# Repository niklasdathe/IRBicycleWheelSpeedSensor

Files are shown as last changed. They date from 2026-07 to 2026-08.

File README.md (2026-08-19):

# IR Spoke Sensor





Configurable 940 nm through-beam spoke sensor for a Seeed Studio XIAO
ESP32-S3. A discrete analog front end restores a 25-50 kHz optical carrier;
ESP-IDF RMT detects its interruption and learns the wheel's spoke pattern.

This repository is the wheel-speed-sensor subsystem of
[BicycleOBU](https://github.com/niklasdathe/BicycleOBU). The
[online Interactive BOM](https://niklasdathe.github.io/IRBicycleWheelSpeedSensor/)
is generated directly from the authoritative KiCad PCB.

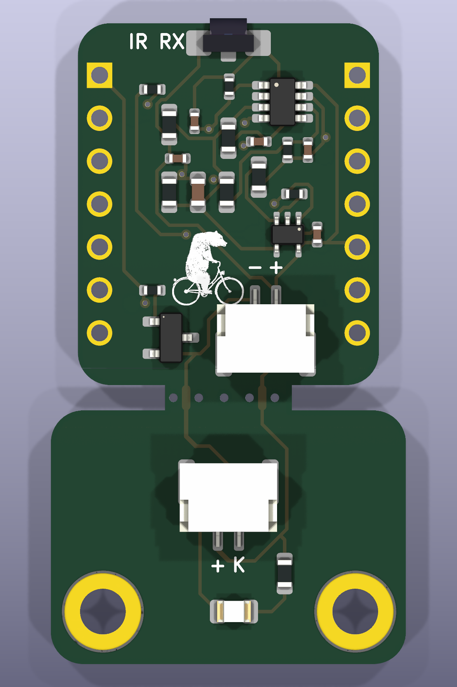
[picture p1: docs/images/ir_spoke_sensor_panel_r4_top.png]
Hardware V0.1 receiver and breakaway emitter panel


## Status

**Hardware V0.1 (KiCad CAD revision R4) was ordered and is preserved as a
[GitHub release](https://github.com/niklasdathe/IRBicycleWheelSpeedSensor/releases/tag/V0.1).
`main` is now hardware V0.2-dev; physical validation is still open for V0.1.**

| Area | Current evidence |
|---|---|
| Hardware | KiCad 10 ERC: 0 errors, 3 known library-sync warnings; DRC: 0 violations, 0 unconnected pads |
| Connectivity | 70 schematic endpoints, PCB pad nets and SPICE topology cross-checked |
| Simulation | Python transient, 10,000-case sweep and ngspice cross-check pass |
| Firmware | Portable core, RMT/CAN adapters and BLE CSC component implemented; ESP32-S3 target build passes, HIL pending |
| Manufacturing | Versioned JLC Gerber/BOM/CPL package generated; assembly-preview approval pending |
| Physical performance | Sunlight, alignment, contamination, vibration and power tests pending |

Do not treat simulation as production validation. The remaining gates are
listed in [TODO.md](TODO.md).

## Start here

| Goal | Guide |
|---|---|
| Understand the signal chain | [System overview](docs/system_overview.md) |
| Open the design or run the simulator | [Getting started](docs/getting_started.md) |
| Change configuration, firmware or captured CAD | [Development workflow](docs/development.md) |
| Order or review the PCB | [Manufacturing](docs/manufacturing.md) |
| Inspect or place components | [Interactive BOM](docs/interactive_bom.html) |
| Bring up and correlate a prototype | [Bring-up and test](docs/bringup.md) |
| Trace a requirement to evidence | [Verification matrix](requirements/verification_matrix.md) |
| Find a technical reference | [Documentation index](docs/README.md) |

## Hardware V0.1 at a glance

| Property | V0.1 value |
|---|---|
| Optical path | 940 nm VSMB1940X01 emitter to VEMD10940FX01 photodiode |
| Carrier | 25-50 kHz runtime range; 38 kHz default; 50% duty |
| Receiver | TLV9062 TIA/band-pass, TLV7011 Schmitt comparator |
| MCU interface | GPIO1 RMT TX, GPIO2 RMT RX with carrier demodulation |
| Wheel design range | 16-48 spokes; 60 km/h requirement, 80 km/h stress calculation |
| Receiver outline | 17.8 x 21.4 mm XIAO outline |
| Emitter outline | 21 x 15 mm, two M2.5 holes |
| Panel | Two-layer PCB with one routed mouse-bite breakaway tab |
| Remote link | 600 mm two-conductor JST-GH harness after snap-off |
| Optional interface | Official XIAO MCP2515 CAN expansion; disabled by default |
| BLE interface | Wheel-only Bluetooth Cycling Speed and Cadence Sensor (`0x1816`) |

## One-command entry points

```powershell
.\Open-IR-Spoke-Sensor.cmd
.\Open-Interactive-BOM.cmd
py -3.14 simulation\local_server.py
powershell -ExecutionPolicy Bypass -File tests\run_all.ps1
powershell -ExecutionPolicy Bypass -File hardware\export_jlc.ps1 -Revision V0.2
```

The KiCad launcher also starts the InteractiveHtmlBom watcher at
`http://127.0.0.1:8766/`; every complete PCB save regenerates and reloads the
browser view. The simulator opens at `http://127.0.0.1:8765/`. Disposable
simulation evidence is written under ignored `build/`.

## Source of truth

| Concern | Authoritative source |
|---|---|
| Tunable system values | [`config/system.json`](config/system.json) |
| Pins and electrical nets | [`hardware/connectivity.json`](hardware/connectivity.json) |
| Parts, fields and procurement | [`hardware/component_catalog.json`](hardware/component_catalog.json) |
| Captured schematic and routing | [`hardware/ir_spoke_link/layout_manifest.json`](hardware/ir_spoke_link/layout_manifest.json) |
| Requirements | [`requirements/requirements.yaml`](requirements/requirements.yaml) |
| Project paths and revision | [`project_manifest.json`](project_manifest.json) |
| Hardware/software versions | [`docs/versioning.md`](docs/versioning.md) |
| Changes between releases | [`CHANGELOG.md`](CHANGELOG.md) |

Generators restore the captured user layout and must not synthesize, remove or
reroute tracks. See [CONTRIBUTING.md](CONTRIBUTING.md) before changing CAD or
generated files.

## License

No project license has been selected yet. Until one is added, the repository
must not be presented as granting open-hardware, software or documentation
reuse rights.

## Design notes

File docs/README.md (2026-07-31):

# Documentation

Start with the row that matches the job in front of you.

## Task guides

| Task | Use this | Result |
|---|---|---|
| Learn what the sensor does | [System overview](system_overview.md) | Signal chain, modulation and boundaries |
| Set up and run the project | [Getting started](getting_started.md) | KiCad, simulator and complete checks |
| Change code, parameters or CAD | [Development workflow](development.md) | Correct source, generator and acceptance gate |
| Fabricate or assemble hardware V0.1 | [Manufacturing](manufacturing.md) | JLC package and review checklist |
| Identify a hardware or software release | [Versioning](versioning.md) | Independent version/tag rules |
| Locate and place components | [Interactive BOM workflow](interactive_bom.md) | Live KiCad-synced HTML BOM |
| Test a physical prototype | [Bring-up and test](bringup.md) | Testpoint sequence and pass evidence |

## Engineering references

| Subject | Reference |
|---|---|
| RMT versus MCPWM decision | [ADR-001](architecture_decision.md) |
| RMT field-to-datasheet traceability | [RMT traceability](rmt_traceability.md) |
| Model and generator relationships | [Executable relationships](model_relationships.md) |
| KiCad/SPICE net contract | [Connectivity contract](connectivity_contract.md) |
| Threshold, testpoints and daylight filter | [Debug and threshold policy](debug_and_threshold.md) |
| Power model | [Power budget](power_budget.md) |
| Optional XIAO CAN interface | [CAN interface](can_interface.md) |
| JLC/Konnect setup | [Konnect and JLCPCB](konnect_jlcpcb.md) |
| Diode assembly polarity | [JLC diode orientation](jlc_diode_orientation.md) |
| Documentation design references | [Reference projects](reference_projects.md) |

## Evidence and machine-readable data

| Artifact | Purpose |
|---|---|
| [`requirements/requirements.yaml`](../requirements/requirements.yaml) | Verifiable requirement statements |
| [Verification matrix](../requirements/verification_matrix.md) | Requirement test and evidence mapping |
| [`datasheet_values.json`](datasheet_values.json) | Extracted limits used by checks |
| [Sources](sources.md) | Primary-source index |
| [`zotero_links.json`](zotero_links.json) | Zotero keys and local attachments |
| [Interactive HTML BOM](interactive_bom.html) | Searchable board/part placement view |
| [Technical simulator reference](../local_simulator/technical.html) | Compact live-model trace definitions |
| [Hardware V0.1 panel image](images/ir_spoke_sensor_panel_r4_top.png) | Ordered CAD R4 PCB |
| [Schematic PDF](../hardware/ir_spoke_link/ir_spoke_link_schematic.pdf) | Current generated schematic |
| [Board STEP](../hardware/ir_spoke_link/ir_spoke_link.step) | Mechanical exchange model |

## Information ownership

Each fact has one owner:

- `config/system.json` owns tunable values.
- `hardware/connectivity.json` owns electrical topology.
- `hardware/component_catalog.json` owns part and procurement metadata.
- `hardware/ir_spoke_link/layout_manifest.json` owns captured layout hashes.
- `requirements/requirements.yaml` owns acceptance requirements.
- `project_manifest.json` owns canonical paths and revision.

Other pages explain or link these values; they must not become independent
configuration sources. `tools/audit_project.py` checks canonical paths,
relative documentation links and index coverage.

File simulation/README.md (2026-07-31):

# Simulation

`ir_spoke_sim.py` is the linked system model. It reads
`../config/system.json`. The local API imports the model directly; command-line
runs write disposable evidence to `../build/simulation/`.

`ir_spoke_link.cir` is the ngspice/KiCad-compatible circuit model. It includes
the remote LED and cable resistance, VEMD10940FX01 photocurrent/capacitance,
TLV9062 finite-bandwidth TIA and active band-pass, TLV7011 hysteretic
comparator, ESP32 load, optional XIAO CAN load and input network. Its physical nets are generated from
`hardware/connectivity.json`. Both batch and local simulations fail when the
generated topology hash is stale.

The fast TLV9062 model in `models/TLV9062_typ_ngspice.lib` uses the
datasheet-typical 100 dB open-loop gain, 10 MHz GBW and 40 mV light-load output
headroom. TI's original PSpice Rev. E ZIP is retained for short sign-off
cases; its switch-heavy model is intentionally not used for the interactive
wheel transient.
`validate_ngspice.py` runs the complete circuit and bounds TIA, band-pass,
blockage-demodulation and current results against the Python reference.

`local_server.py` serves `http://127.0.0.1:8765/`. The HTML contains no
second electrical model: `/api/simulate` calls `ir_spoke_sim.simulate()`
directly. Every window is phase-aligned to contain a complete spoke blockage.
Reset reloads `config/system.json`; code export runs the same transient and
returns a C header containing the selected RMT and adaptive-map values.

Current/power traces separate LED, ESP32, AFE and optional CAN loads and include carrier
edges, a Wi-Fi TX burst, configurable CPU activity, VREF startup and local
decoupling inrush. The local UI exposes CAN enable and dominant-bus duty and
uses the same values when generating the experiment header. See
`docs/power_budget.md` for assumptions and limitations.

Run:

```powershell
py -3.14 simulation/ir_spoke_sim.py
py -3.14 simulation/validate_ngspice.py
py -3.14 tools/validate_kicad_netlist.py
py -3.14 simulation/local_server.py
```

The numerical noise source combines ambient/dark-current shot noise, TIA
feedback-resistor Johnson noise, op-amp current noise, an input-referred
approximation of op-amp voltage noise, and the separately adjustable
environmental interference term. The model has no proprietary integrated
receiver behavior. Beam profile, contamination, sunlight spectra and
mechanical alignment still require prototype tests before release.

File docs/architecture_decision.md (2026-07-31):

# ADR-001: RMT RX instead of MCPWM Capture for the raw comparator carrier

Status: accepted for the current hardware.

The custom analog front end intentionally stops at a Schmitt comparator. Its
output is therefore a clean logic carrier at the selected 25–50 kHz transmit
frequency whenever the optical path is clear and stops while a spoke blocks
the beam.

ESP32-S3 RMT is the better fit for that signal because the peripheral supports
TX carrier modulation, RX carrier demodulation, input filtering and
symbol-duration capture. The firmware uses ESP-IDF's official channel,
copy-encoder, carrier, callback, receive and transmit abstractions instead of
register access. It receives missing-carrier windows without processing every
carrier edge in an application ISR.

The RX demodulator frequency is derived at runtime as a configurable ratio of
the selected TX frequency. The default 0.66 follows Espressif's documented
38 kHz TX / 25 kHz RX tolerance example and is not a second fixed frequency.
TX and RX GPIO, RMT resolution, channel memory, TX queue depth, carrier duty,
RX ratio/duty, minimum pulse, blockage acceptance and link-loss timeout are all
members of the validated runtime configuration. Callback timestamps are
reconstructed from captured RMT symbol durations instead of assigning the
callback time to every event.

MCPWM Capture has a high-resolution APB-clock timestamp and is excellent when
the input is already a baseband edge. On ESP32-S3 its requested resolution is
ignored because the capture timer uses the APB source. Using it here would
either expose every carrier edge to the capture path or require another analog
envelope detector. That adds parts without improving spoke-time accuracy.

Revisit this decision only if a future board adds an external envelope detector,
or if RMT resources are consumed by another subsystem.

The 25–50 kHz range is an engineering constraint of the installed analog
filter, not a protocol requirement. Values outside it are rejected by
`ir_spoke_config_validate()`.

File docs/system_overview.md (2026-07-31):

# System overview

## Purpose

The sensor measures spoke passages by shining a modulated infrared beam across
the wheel. A spoke briefly blocks the beam. The receiver converts the missing
carrier interval into a timestamped digital event for an ESP32-S3.

This is carrier-presence sensing, not an IR data protocol.

## Signal chain

```mermaid
flowchart LR
  A["ESP32-S3 RMT TX<br>25-50 kHz"] --> B["S8050 LED driver"]
  B --> C["940 nm side-view LED"]
  C --> D{"Spoke blocks beam?"}
  D --> E["VEMD10940FX01<br>photodiode"]
  E --> F["TLV9062 TIA"]
  F --> G["TLV9062 band-pass"]
  G --> H["TLV7011 comparator<br>with hysteresis"]
  H --> I["ESP32-S3 RMT RX<br>carrier demodulation"]
  I --> J["Blockage detector"]
  J --> K["Spoke-count inference<br>adaptive interval LUT"]
  K --> L["Application / optional CAN"]
```

The main board and emitter are initially one routed panel. After functional
test, the emitter snaps off and reconnects through the two-conductor JST-GH
harness.

## Modulation

RMT TX drives the LED with a 50% duty square carrier. With a clear beam, the
photodiode and analog front end recover that periodic energy and the comparator
produces logic edges. A spoke removes several carrier cycles. RMT RX
demodulation converts that carrier loss into a single interval for the
detector.

Modulation improves reliability because:

- the AC-coupled band-pass rejects DC and slowly changing ambient light;
- energy in a known frequency range is easier to distinguish from broadband
  noise than unmodulated intensity;
- comparator hysteresis suppresses repeated transitions near threshold;
- RMT filters and demodulates in hardware, so the application processes
  blockage intervals instead of every carrier edge.

The photodiode includes a daylight-blocking optical filter, but sunlight still
contains 940 nm energy. Modulation reduces ambient sensitivity; it does not
remove the need for physical sunlight testing.

## Timing and adaptation

The configured design range is 16-48 spokes at up to 60 km/h, with an 80 km/h
stress calculation. The detector accepts only blockage widths inside the
configured interval. Accepted timestamps feed a portable pattern module that:

1. rejects outliers;
2. estimates the repeating spoke count;
3. maintains one expected interval per spoke in a bounded LUT;
4. updates the LUT continuously with exponential adaptation.

Uniformly spaced spokes do not contain enough information to identify an
absolute spoke index. The implementation reports confidence and keeps adapting
instead of requiring a manual calibration.

## Model boundary

The executable models include wheel geometry, optical coupling, photodiode
current/capacitance, analog bandwidth and noise, comparator behavior, RMT
timing, power transients and optional CAN load. Python supplies the interactive
and tolerance model; ngspice cross-checks the electrical transient.

They do not prove real beam alignment, lens/fixture tolerances, spectral
sunlight rejection, water/dirt behavior, cable vibration or component aging.
Those are explicit prototype tests in [Bring-up and test](bringup.md).

## Interfaces

| Boundary | Contract |
|---|---|
| Tunable model to generated code | `config/system.json` |
| Schematic/PCB to SPICE | `hardware/connectivity.json` |
| Comparator to MCU | GPIO2, RMT RX symbols |
| Detector to pattern learner | accepted event timestamp and blockage width |
| Pattern learner to application | count, confidence, phase and interval LUT |
| Application to CAN adapter | transport-independent fixed telemetry frame |

Detailed interfaces are in
[`firmware/components/ir_spoke_core`](../firmware/components/ir_spoke_core/)
and [Executable relationships](model_relationships.md).

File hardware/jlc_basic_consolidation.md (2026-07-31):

# JLCPCB part-class and consolidation audit

Checked 2026-07-28 against the JLCPCB Parts API snapshot in
`hardware/jlcpcb_parts_snapshot.json`.

| Group | Result |
|---|---|
| Basic retained | Q1; R2, R3, R4, R5, R7, R9, R10, R11; C1, C3, C5, C6 |
| Extended retained for analog value/dielectric | R6 16 kOhm, R8 560 kOhm, C2 120 pF C0G, C4 4.7 pF C0G |
| Extended retained for electrical/optical behavior | D1, D2, U1, U2 |
| Extended retained for mechanics | J3 and J4, consolidated to one identical JST-GH part |
| Extended retained for LED current | R1 39 Ohm; no exact in-stock Basic result was returned |

The active devices are model inputs, not generic placeholders. Replacing
TLV9062, TLV7011, VEMD10940FX01 or VSMB1940X01 requires a new
datasheet-value extraction, tolerance sweep, transient simulation and optical
alignment review. J3/J4 and their cable parts are already consolidated.

The current placed panel has 24 placements in 20 grouped BOM rows. Common
passives and Q1 are Basic. Header sockets, M2.5 holes and test pads are DNI.

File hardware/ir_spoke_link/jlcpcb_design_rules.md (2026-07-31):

# JLCPCB manufacturing profile

Conservative 2-layer, 1 oz rules used by this project:

- Track width / clearance: 0.15 / 0.15 mm (fab minimum is 0.10 / 0.10 mm).
- Signal vias: 0.60 mm diameter, 0.30 mm drill.
- Via-to-track: 0.25 mm (fab minimum 0.20 mm).
- Different-net SMD pad clearance: 0.20 mm (fab minimum 0.15 mm).
- Copper-to-board-edge: 0.30 mm.
- Minimum component body-to-edge target: 2.5 mm where the XIAO carrier
  geometry allows; the optical edge-facing parts require explicit DFM review.
- 0402 is the smallest passive footprint used. 0603 is used for the LED current
  resistor to retain pulse-power margin.
- IPC-7351 medium-density courtyards; no via-in-pad.
- Exactly two copper layers, 1.6 mm FR-4 and 1 oz outer copper are encoded in
  the R4 order definition.
- The receiver is 17.8 x 21.4 mm; the transmitter is 21 x 15 mm. Both have
  four 1.905 mm-radius corners.
- One 7.5 x 1.5 mm routed tab joins the boards. Five 0.5 mm NPTH drills at
  1.5 mm pitch form the break line. Two 0.25 mm temporary links cross between
  the drills and are intentionally severed when the tab is snapped.
- The combined customer board is 21 x 37.9 mm and requires online DFM review
  of the mouse-bite tab before ordering.
- BOM, CPL, Gerber job, copper, mask, silkscreen, outline and drill files are
  included by the versioned `IR_Spoke_Sensor_R4_2L` export workflow.

Sources are recorded in `docs/sources.md`. Always re-run JLCPCB online DFM and
re-check live component stock immediately before ordering.

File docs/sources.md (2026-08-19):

# Sources and assumptions

## Geometry

- 700C / 29-inch class effective rolling diameter assumed: 0.702 m.
- Maximum design speed: 60 km/h; stress case: 80 km/h.
- 32 round spokes, 2.0 mm projected width.
- Optical crossing radius: 0.25 m from hub.

At 60 km/h this gives 7.56 wheel revolutions/s, 241.9 spoke passages/s,
approximately 168 µs blocked per spoke and 3.97 ms clear between spokes.

## Primary references

- Bluetooth SIG, *Cycling Speed and Cadence Profile 1.0* (with mandatory Errata
  Correction 23224): https://www.bluetooth.com/specifications/specs/cycling-speed-and-cadence-profile-1-0/
- Bluetooth SIG, *Cycling Speed and Cadence Service 1.0.1*:
  https://www.bluetooth.com/specifications/specs/cycling-speed-and-cadence-service/

- JLCPCB PCB capabilities:
  https://jlcpcb.com/capabilities/pcb-capabilities/
- JLCPCB PCB assembly FAQ and Basic/Extended classification:
  https://jlcpcb.com/help/article/pcb-assembly-faqs
- JLCPCB assembly DFM terms:
  https://jlcpcb.com/help/article/terms-and-conditions-of-jlcpcb-assembly-service
- Vishay VSMB1940X01 940 nm IR LED, LCSC C3151600:
  https://www.lcsc.com/product-detail/C3151600.html
- Vishay VEMD10940FX01 side-view photodiode, LCSC C7104273:
  https://www.vishay.com/docs/84217/vemd10940fx01.pdf
- Vishay packaging and tape orientation (VSMB1940X01 Fig. 32):
  https://www.vishay.com/docs/80090/packaging.pdf
- JLCPCB placement rotation and zero-orientation rules:
  https://jlcpcb.com/help/article/pick-place-file-for-pcb-assembly
  https://jlcpcb.com/help/article/pcb-assembly-faqs-part-2
- TI TLV9062 10 MHz RRIO dual op amp, LCSC C2867884:
  https://www.ti.com/lit/ds/symlink/tlv9062.pdf
- TI TLV7011 nanopower comparator, LCSC C193688:
  https://www.ti.com/lit/ds/symlink/tlv7011.pdf
- JST GH 1.25 mm side-entry secure-lock header
  SM02B-GHS-TB(LF)(SN), LCSC/JLCPCB C189893:
  https://www.jst-mfg.com/product/pdf/eng/eGH.pdf
- Live LCSC listing for SM02B-GHS-TB(LF)(SN):
  https://www.lcsc.com/product-detail/wire-to-board-connector_jst-sm02b-ghs-tb-lf-sn_C189893.html
- ESP32-S3 RMT peripheral:
  https://docs.espressif.com/projects/esp-idf/en/stable/esp32s3/api-reference/peripherals/rmt.html
- ESP32-S3 datasheet, revision 2.2:
  https://documentation.espressif.com/esp32-s3_datasheet_en.pdf
- Espressif ESP32-S3 hardware design guidelines:
  https://documentation.espressif.com/projects/esp-hardware-design-guidelines/en/latest/esp32s3/schematic-checklist.html
- Seeed Studio XIAO ESP32-S3 getting started / 3V3 capacity:
  https://wiki.seeedstudio.com/xiao_esp32s3_getting_started/
- Official Seeed Studio XIAO CAN Bus Expansion board, pin map and design:
  https://wiki.seeedstudio.com/xiao-can-bus-expansion/
- Microchip MCP2515 stand-alone CAN controller:
  https://files.seeedstudio.com/wiki/xiao_can_bus_board/MCP2515-Stand-Alone-CAN-Controller-with-SPI-200018-708845.pdf
- TI SN65HVD230 3.3 V CAN transceiver:
  https://www.ti.com/lit/ds/symlink/sn65hvd230.pdf
- JLCPCB V-cut panelization standards:
  https://jlcpcb.com/blog/v-cut-panelization-standards
- JLCPCB Gerber preparation:
  https://jlcpcb.com/help/article/gerber-files-preparation

## Engineering status

LCSC stock and JLCPCB library class are live commercial data and can change
without notice. The BOM captures the checked candidate set, but it is not a
purchase guarantee. Active performance parts are Extended; common passives and
the S8050 driver are Basic. Direct-sun, alignment, vibration, dirt and water
tests are required before treating the link as safety-related.

The official CAN expansion's Eagle design identifies MCP2515 plus
SN65HVD230; its D6/D7/D8/D9/D10 assignment is disjoint from this sensor's
D0/D1 RMT assignment. The optional CAN power case is included in the
simulation even though the CAN board is not populated on the sensor panel.

The VEMD10940FX01 datasheet specifies a daylight-blocking filter matched to
830-950 nm emitters. This reduces visible/daylight loading but cannot reject
the 940 nm content of direct sunlight; electrical AC filtering and physical
sunlight tests remain necessary.

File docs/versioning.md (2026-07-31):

# Versioning and releases

Hardware and software have independent version streams.

| Stream | Version file | GitHub tag format | Meaning |
|---|---|---|---|
| Hardware | `hardware/VERSION` | `V0.1`, `V0.2`, ... | Ordered or manufactured PCB baseline |
| Software | `firmware/VERSION` | `SW-V0.1.0`, ... | Tested firmware release |

KiCad CAD revision `R4` is an internal design identifier. Hardware `V0.1` is
the ordered release made from that CAD revision. A hardware release never
implies that firmware with a similar number was released.

The `V0.1` annotated Git tag and GitHub release are immutable troubleshooting
anchors. The release contains the combined order package, Gerber archive,
PCBA archive, individual BOM/CPL/order files, DRC evidence, courtyard reference
and SHA-256 checksums.

Development after the ordered baseline uses `V0.2-dev` in
`hardware/VERSION`. Its changelog section records differences relative to
`V0.1`; only an intentionally approved manufacturing state becomes tag `V0.2`.

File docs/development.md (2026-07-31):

# Development workflow

## Rule: change the owner, not a consumer

| Concern | Authoritative input | Generated or checked consumers |
|---|---|---|
| Timing, optical, analog and power values | `config/system.json` | C headers, SPICE parameters, Python/UI defaults |
| Pins and nets | `hardware/connectivity.json` | KiCad audit and SPICE connectivity include |
| Parts and fields | `hardware/component_catalog.json` | schematic/PCB fields, BOM, footprint and Konnect data |
| Requirements | `requirements/requirements.yaml` | verification matrix and tests |
| Manual CAD state | live KiCad files | captured layout templates and hashes |

Never edit a generated consumer to override its source.

## Parameter change

1. Edit `config/system.json`.
2. Run `py -3.14 tools/generate_constants.py`.
3. Exercise the value in the local simulator.
4. Add or update a requirement/test if acceptance behavior changed.
5. Run `tests/run_all.ps1`.

The runtime carrier remains validated from 25-50 kHz. The generated header
provides compile-time defaults and limits; it does not replace runtime
validation.

## Firmware boundaries

`firmware/components/ir_spoke_core` is portable C99 with caller-owned state and
no heap, RTOS or ESP-IDF dependency:

| Module | Interface responsibility |
|---|---|
| `ir_spoke_config` | Validate runtime carrier and detector configuration |
| `ir_spoke_geometry` | Convert wheel geometry and speed to timing |
| `ir_spoke_detector` | Qualify blockage widths and track link state |
| `ir_spoke_pattern` | Infer count/confidence and adapt the interval LUT |
| `ir_spoke_pipeline` | Compose detector and learner without hardware access |
| `ir_spoke_can` | Encode fixed telemetry independently of transport |

`firmware/main` owns ESP-IDF RMT and optional MCP2515/SPI integration. Hardware
callbacks translate peripheral events into the portable interfaces; portable
modules do not call ESP-IDF.

## Connectivity change

1. Edit `hardware/connectivity.json`.
2. Update the schematic/PCB manually if the physical design changes.
3. Run `py -3.14 tools/generate_connectivity.py`.
4. Run `py -3.14 tools/validate_kicad_netlist.py`.
5. Run the full suite.

Simulation refuses to start when its topology hash is stale. The native KiCad
netlist, PCB pad nets and generated SPICE topology must all match.

## CAD change

The route is user-authored and protected. Generators may restore it but must
never route.

1. Open through `Open-IR-Spoke-Sensor.cmd`.
2. Make the manual schematic, placement or routing edit.
3. Save and close every KiCad editor.
4. Run:

   ```powershell
   py -3.14 hardware\ir_spoke_link\capture_layout.py
   ```

5. Review the PDF/PCB visually and run the complete suite.

6. Regenerate the README image from the captured board:

   ```powershell
   py -3.14 tools\readme_pcb_render.py --generate
   ```

`layout_manifest.json` records schematic, PCB, logical routing, raw route text,
preferences, rotations, DRC requirements and endpoint count. A component move
does not authorize automated rerouting.

The render manifest beside the PNG records both the PCB and image hashes. CI
fails when the README still shows an older captured PCB.

## Acceptance checklist

- [ ] The authoritative source changed.
- [ ] Generated files were regenerated, not manually patched.
- [ ] Relevant requirement and test still express the intended behavior.
- [ ] `tests/run_all.ps1` passes.
- [ ] CAD hashes changed only when an intentional manual CAD edit occurred.
- [ ] Physical claims remain marked unverified until measured.
- [ ] Manufacturing changes pass the [manufacturing checklist](manufacturing.md).

See [CONTRIBUTING.md](../CONTRIBUTING.md) for the concise repository policy.

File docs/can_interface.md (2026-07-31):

# Optional XIAO CAN interface

Hardware: official Seeed XIAO CAN Bus Expansion Board, SKU 105100001,
MCP2515 controller with 16 MHz crystal and SN65HVD230 3.3 V transceiver.

| XIAO pin | ESP32-S3 GPIO | CAN function | IR conflict |
|---|---:|---|---|
| D6 | 43 | MCP2515 INT | none |
| D7 | 44 | MCP2515 CS | none |
| D8 | 7 | SPI SCK | none |
| D9 | 8 | SPI MISO | none |
| D10 | 9 | SPI MOSI | none |
| D0 | 1 | IR RMT TX | CAN unused |
| D1 | 2 | IR RMT RX | CAN unused |

Default CAN bitrate: 500 kbit/s. SPI: 10 MHz, mode 0. Compile-time
`_Static_assert` checks prevent future IR/CAN pin overlap.

Interfaces:

- `ir_spoke_can`: portable frame encoding and caller-supplied send callback.
- `ir_spoke_can_mcp2515_adapter`: ESP-IDF `spi_master` and MCP2515 register
  protocol for the official board.
- `ir_spoke_rmt_adapter`: publishes one estimate frame after each accepted
  blockage when the CAN publisher is enabled.

Standard ID `0x180` payload:

| Byte | Field | Encoding |
|---:|---|---|
| 0 | inferred spoke count | unsigned |
| 1 | current spoke index | unsigned |
| 2–3 | wheel frequency | little-endian mHz |
| 4–5 | blockage duration | little-endian µs |
| 6–7 | confidence | little-endian per mille |

`config/system.json` is authoritative. `tools/generate_constants.py` writes
the pin map, oscillator, bitrate, SPI clock, enable default and CAN ID into
firmware and SPICE constants. The localhost simulator exposes CAN enable and
bus-duty inputs and plots `can_current_ma`.

Official sources and Zotero keys are recorded in
`docs/zotero_links.json`.

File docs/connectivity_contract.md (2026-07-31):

# Connectivity contract

`hardware/connectivity.json` is the canonical pin-to-net definition for both
boards and the two resistive harness conductors.

Consumers and gates:

- `hardware/ir_spoke_link/capture_layout.py` through the native netlist gate;
- the hash-verified main-board schematic/PCB layout templates;
- `tools/generate_connectivity.py` for SPICE;
- `hardware/footprint_audit.py`.

`tools/validate_kicad_netlist.py` independently asks KiCad to export its native
XML netlist and compares all 70 connected schematic pins with the manifest.
`simulation/connectivity_guard.py` hashes the manifest and refuses every batch
or local API simulation if `simulation/generated_connectivity.inc` is stale.

This catches symbol transforms, swapped active-device pins, connector mistakes,
PCB pad-net drift and stale SPICE topology. It does not prove track routing:
KiCad DRC remains the routing gate. After restoring the physical footprint
orientations and moving the correction into CPL-only rotation offsets, both
the combined receiver/emitter panel has zero findings and zero open
connections. Its layout capture
additionally freezes the 197 user segments, 12 vias and raw route-expression
SHA-256.

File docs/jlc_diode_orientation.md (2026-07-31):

# JLC diode orientation verification

JLC CPL rotation is positive counter-clockwise. JLC defines package zero from
the tape/reel orientation and requires the assembly preview and polarity marks
to be checked.

| Ref | Part | Physical KiCad zero | LCSC-owned EasyEDA package zero | CPL offset | Final CPL |
|---|---|---|---|---:|---:|
| D1 | VSMB1940X01 / C3151600 | pad 1 cathode left; pad 2 anode right | pin/pad 1 anode left; pin/pad 2 cathode right | 180° | 180° |
| D2 | VEMD10940FX01 / C7104273 | pad 1 cathode left; pad 2 mechanical center; pad 3 anode right | pin/pad 1 cathode left; pin/pad 2 mechanical center; pin/pad 3 anode right | 0° | 0° |

Electrical maps:

- D1.1 = `LED_K_REMOTE`, D1.2 = `LED_A`.
- D2.1 = `+3V3`, D2.2 = `NC_MECHANICAL`, D2.3 = `PD_ANODE`.

The LCSC package records were read from:

- `https://easyeda.com/api/products/C3151600/components?version=6.5.37`
- `https://easyeda.com/api/products/C7104273/components?version=6.5.37`

Both records identify `owner.username = lcsc`. C3151600's EasyEDA symbol maps
pin 1 to A and pin 2 to K, while KiCad's LED convention maps pad 1 to K and pad
2 to A. D1 therefore needs a CPL-only 180° correction. C7104273 maps pin 1 to
the cathode and pin 3 to the anode, so D2 needs no correction.

The generator binds each rotation rule to reference, LCSC number and MPN and
aborts if those fields no longer match. `hardware/footprint_audit.py`
independently verifies physical rotation and diode pad/net polarity. In the JLC
assembly preview, both parts must read cathode on the left and anode on the
right (`- D1 +` and `- D2 +`).

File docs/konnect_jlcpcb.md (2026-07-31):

# Konnect JLCPCB database connection

In **Konnect Settings**:

1. Leave `kicad-cli` at
   `C:\Program Files\KiCad\10.0\bin\kicad-cli.exe`.
2. Set `JLCPCB DB` to
   `%APPDATA%\konnect\jlcpcb.db`.
3. Leave `IPC Socket` empty for normal automatic discovery.
4. Keep `Transport` at `both`, click **Save**, then close the dialog.

The screenshot already shows the server running. KiCad must be open with IPC
available for live editor operations.

Konnect's effective-config API was queried after setup and returns this exact
database path plus `prefer_jlc_basic: true` and the project JLCPCB rules.

The database currently contains 21 integrity-checked rows used by this
project: 9 Basic and 12 Extended. It is deliberately a project-BOM subset,
not the complete JLCPCB catalog.

Rebuild and verify:

```powershell
py -3.14 tools\refresh_jlc_links.py
py -3.14 tools\build_konnect_jlc_db.py
py -3.14 -m unittest tests.test_system.TestSystem.test_konnect_database_matches_expected_schema_and_scope -v
```

After a rebuild, restart the Konnect server if it does not notice the replaced
SQLite file. `hardware/konnect_database_manifest.json` records scope, counts,
source timestamp and SHA-256.

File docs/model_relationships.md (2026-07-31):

# Executable relationships

| Source | Generated or checked consumers |
|---|---|
| `config/system.json` | firmware headers, SPICE parameters, Python defaults, local UI reset |
| `hardware/connectivity.json` | schematic/PCB audits, native KiCad netlist gate, SPICE topology and topology hash |
| `hardware/component_catalog.json` | schematic/PCB fields, BOM, footprint audit and JLC/Konnect metadata |
| `docs/datasheet_values.json` | model limits, requirements checks and technical documentation |
| `hardware/ir_spoke_link/*.layout.kicad_*` | byte-identical schematic/PCB/preferences regeneration |
| `hardware/ir_spoke_link/layout_manifest.json` | layout, route, rotations, DRC and net-endpoint integrity gates |
| `simulation/ir_spoke_sim.py` | local API, generated experiment header and batch evidence |
| `simulation/ir_spoke_link.cir` | ngspice cross-check against the Python transient |
| `requirements/requirements.yaml` | verification-ID coverage in `requirements/verification_matrix.md` |
| `hardware/ir_spoke_link/bom_jlcpcb.csv` | R4 export, live JLC snapshot and Konnect project database |

The combined PCB is the only emitter-board source. The breakaway transmitter is
part of the same captured board, BOM, CPL, connectivity contract and DRC gate.
Generated simulation results live under `build/`; the source tree contains no
second cached simulation dataset.

Run `tools/audit_project.py` for path/reference integrity and
`tests/run_all.ps1` for the complete executable chain.

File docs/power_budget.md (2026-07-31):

# Power budget

## Modeled 3.3 V rail

| Load | Default scenario |
|---|---:|
| ESP32-S3 + XIAO board, averaged | 60.35 mA |
| IR LED, 45.02 mA peak at 50% duty | 22.51 mA |
| S8050 base drive, 2.50 mA peak at 50% duty | 1.25 mA |
| TLV9062, TLV7011 and VREF divider | 1.246 mA |
| Optional XIAO CAN board | 0 mA (disabled by default) |
| Total steady average | 85.36 mA |
| Total coincident peak estimate | 392.27 mA |
| 3.3 V steady power | 281.69 mW |
| Estimated regulator input at 90% efficiency | 312.99 mW |

The ESP32 scenario uses the datasheet's 42.3 mA WAITI and 54.6 mA
single-core values at 160 MHz, a configurable 10% CPU-active fraction, and a
configurable 5% Wi-Fi TX fraction. The peak aligns the 340 mA 802.11b/21 dBm
case with LED, base, AFE, VREF and local-bypass startup currents.

The estimated peak is 78.5% of Espressif's 500 mA minimum recommended supply
capacity and 56.0% of Seeed's stated 700 mA XIAO 3V3 output capacity. GPIO1
sources 2.5 mA peak, 6.25% of the ESP32-S3 datasheet's 40 mA typical source
test point. These comparisons pass for the modeled scenario.

## Optional official XIAO CAN expansion

The CAN option uses the board's MCP2515 and SN65HVD230. The conservative
enabled model includes 10 mA MCP2515 active current, 17 mA transceiver
recessive current, 8 mA board-LED allowance and an additional estimated
33 mA while driving a dominant, 60-ohm-terminated bus.

| CAN case | CAN load | System average | Coincident peak |
|---|---:|---:|---:|
| Enabled, 10% dominant duty | 38.3 mA average / 68 mA peak | 123.66 mA | 460.27 mA |
| Enabled, 100% dominant stress | 68 mA | 153.36 mA | 460.27 mA |

The stress peak uses 92.1% of the 500 mA ESP32-S3 supply recommendation and
65.8% of the stated 700 mA XIAO 3V3 capacity. It passes the configured limits,
but the 39.7 mA margin to 500 mA is small enough that the CAN+Wi-Fi+LED
coincident case must be measured before release.

## Transients and limits

`simulation/ir_spoke_sim.py` exposes `led_current_ma`,
`esp32_current_ma`, `afe_current_ma`, `can_current_ma`, `system_current_ma` and
`supply_voltage_v` and `system_power_mw`. It includes:

- carrier-cycle LED and transistor-base current;
- a centered Wi-Fi current burst;
- event-related CPU activity;
- 200 nF local bypass charging during the configured supply rise;
- VREF capacitor charging through the 10 kOhm divider;
- comparator/GPIO capacitive edge current.

The model does not claim the XIAO module's complete USB-plug-in inrush because
the onboard regulator, bulk capacitance, source impedance and cable are not
characterized here. Verify the assembled board with a current probe or shunt,
including Wi-Fi TX, cold power-up and worst supply cable, before release.

Primary values: `docs/datasheets/ESP32-S3_Datasheet.pdf`,
`docs/datasheets/TLV9062.pdf`, `docs/datasheets/TLV7011.pdf`.

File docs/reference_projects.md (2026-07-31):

# Documentation reference projects

Reviewed 2026-07-31. These are reference patterns, not a universal ranking.
They were selected because each makes a mature hardware project easy to enter
without requiring a large front page.

## Framework Laptop 13

Repository:
[FrameworkComputer/Framework-Laptop-13](https://github.com/FrameworkComputer/Framework-Laptop-13)

Useful pattern: a one-sentence scope followed by direct, module-oriented links
to CAD, drawings, connector pinouts and electrical documentation. Licensing is
visible near the top.

Applied here: the root README now routes directly to system, development,
manufacturing, testing and authoritative artifacts instead of narrating the
repository history.

## Libre Solar BMS C1

Repository:
[LibreSolar/bms-c1](https://github.com/LibreSolar/bms-c1)

Useful pattern: prototype maturity is visible immediately, followed by direct
links to schematic, BOM, interactive BOM, firmware, manual, mechanical files
and a test report. Hardware and documentation licenses are explicit.

Applied here: R4 status separates automated evidence from pending physical
validation, and manufacturing/test artifacts are reachable from the first
page.

## HackRF

Repository:
[greatscottgadgets/hackrf](https://github.com/greatscottgadgets/hackrf)

Useful pattern: hardware, firmware, host software and documentation have clear
top-level ownership. The README directs users to built documentation,
troubleshooting and the exact local documentation build command.

Applied here: task guides own procedures, technical references own rationale,
and the getting-started guide states commands plus expected outcomes.

## LumenPnP

Repository:
[opulo-inc/lumenpnp](https://github.com/opulo-inc/lumenpnp)

Useful pattern: stable releases are distinguished from development branches;
exported fabrication artifacts are attached to releases; the roadmap defines
completion in terms of BOM, build guide, usage guide and lifetime tests.

Applied here: R4 is called a release candidate rather than a validated product,
the JLC output is versioned, and physical validation remains a visible release
gate.

## Adopted documentation rules

1. State purpose and maturity before detail.
2. Navigate by user task, not only by file type.
3. Link directly to usable hardware artifacts.
4. Separate generated evidence, inspection and physical measurement.
5. Give every value and relationship one authoritative owner.
6. Put exact commands beside their expected result.
7. Keep release artifacts versioned and development state clearly marked.
8. Make licensing status explicit.

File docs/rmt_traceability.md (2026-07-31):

# ESP32-S3 RMT traceability

- Zotero parent item: `C5MIHHD4`
- Zotero PDF attachment: `BC9PFKHQ`
- Local mirror: `docs/datasheets/ESP32-S3_TRM.pdf`
- Document: ESP32-S3 TRM, version 1.8, chapter 37
- Driver API cross-check: current stable ESP-IDF Programming Guide v6.0.2
- Hardware relationships used: TX modulation, RX demodulation, RX filtering,
  duration-coded receive symbols.
- ESP-IDF API relationships used: `rmt_new_tx_channel`,
  `rmt_new_rx_channel`, `rmt_new_copy_encoder`, `rmt_apply_carrier`,
  `rmt_rx_register_event_callbacks`, `rmt_enable`, `rmt_receive`,
  `rmt_transmit`.
- RX default: `round(0.66 * f_TX)`. This is the configurable rounded form of
  Espressif's Programming Guide tolerance example (38 kHz TX, 25 kHz RX).
- Captured duration conversion:
  `duration_us = round(duration_ticks * 1e6 / rmt_resolution_hz)`.
- The callback time is the end of the receive transaction. Event starts are
  reconstructed backwards from all returned symbol durations, then advanced
  phase by phase.

The TRM establishes that the ESP32-S3 hardware supports this demodulation.
ESP-IDF supplies the supported software abstraction; no RMT registers are
accessed directly.

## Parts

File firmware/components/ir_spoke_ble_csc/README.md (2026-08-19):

# BLE Cycling Speed and Cadence sensor

ESP-IDF 5.x/NimBLE wheel-only Sensor implementation of Bluetooth CSC Profile
1.0 and Service 1.0.1. This component follows the repository's ESP-IDF
component boundary: `app_main` starts it once and the RMT adapter forwards only
completed wheel revolutions after the spoke-pattern estimator is locked.

`register_service()` rejects duplicate registration, preserving the profile's
requirement for exactly one primary CSC service instance.

The public C API is:

```c
ESP_ERROR_CHECK(ir_spoke_ble_csc_start());
ir_spoke_ble_csc_on_wheel_revolution(timestamp_us);
```

The component owns NimBLE initialization, its GAP Peripheral lifecycle,
connectable advertising, subscription tracking, and reconnect advertising.
Notifications are rate-limited to the profile's typical one-second interval.

The module provides CSC Measurement, wheel-only CSC Feature, and the mandatory
Set Cumulative Value control-point procedure, including the required 0x80/0x81
application errors and one-procedure-at-a-time indication lifecycle. Counts
saturate at `UINT32_MAX`; event time uses 1/1024 seconds and rolls over every
64 seconds. Calls into the wheel state are serialized across the RMT and NimBLE
host tasks.

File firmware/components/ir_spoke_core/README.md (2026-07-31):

# ir_spoke_core

Portable C99; no heap, RTOS or ESP-IDF dependency.

- `ir_spoke_geometry`: wheel/spoke timing calculation.
- `ir_spoke_config`: validated runtime carrier/demodulation configuration.
- `ir_spoke_detector`: blockage-width acceptance and counters.
- `ir_spoke_pattern`: count inference, confidence and adaptive interval LUT.
- `ir_spoke_pipeline`: explicit detector-to-pattern composition boundary.
- `ir_spoke_can`: transport-independent fixed-frame telemetry publisher.

Inputs are integer microsecond timestamps/durations. State is caller-owned.
Each module can be host-tested without GPIO or RMT hardware.

The ESP-IDF layer owns RMT and the official XIAO MCP2515 SPI protocol. CAN is
disabled by default and can be enabled through the generated system baseline.

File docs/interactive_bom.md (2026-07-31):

# Interactive BOM

[Open the generated Interactive HTML BOM](interactive_bom.html).

The page is generated directly from
`hardware/ir_spoke_link/ir_spoke_link.kicad_pcb`. It contains the front board
drawing, fabrication/silkscreen/pads, tracks, nets, placement checkboxes and a
searchable grouped BOM with manufacturer, MPN, LCSC and JLC classification.
Clicking a BOM row highlights the footprint; entering a reference such as
`D1` in **Ref lookup** selects it on the board.

## Live KiCad synchronization

Run:

```powershell
.\Open-Interactive-BOM.cmd
```

The watcher serves `http://127.0.0.1:8766/interactive_bom.html`, monitors the
authoritative PCB and regenerates after every complete save. The served page
reloads automatically when its output hash changes. Opening the normal KiCad
launcher starts the same watcher before Pcbnew.

The committed HTML remains fully self-contained and works offline without the
watcher. Browser checkbox state is local to the browser and is not part of the
KiCad design.

## Reproduce or verify

The setup script installs the pinned upstream release outside the repository:

```powershell
powershell -ExecutionPolicy Bypass -File tools\setup_interactive_bom.ps1
py -3.14 tools\interactive_bom.py --generate
py -3.14 tools\interactive_bom.py --check
```

The tool is pinned to
[openscopeproject/InteractiveHtmlBom v2.11.2](https://github.com/openscopeproject/InteractiveHtmlBom/releases/tag/v2.11.2),
commit `de7fad7ead9b73cea7eb17afa02c6ce9ce17a6ab`. The generator runs with KiCad
10's bundled Python/`pcbnew`, so board parsing uses the same KiCad major
version as the project.

`interactive_bom.json` records the PCB SHA-256, HTML SHA-256, generator
version and complete option list. Repository checks fail if either file is
stale or modified independently.

## Publication

GitHub Pages publishes the `docs/` directory. After Pages is enabled for the
repository, the stable URL is:

`https://niklasdathe.github.io/IRBicycleWheelSpeedSensor/interactive_bom.html`

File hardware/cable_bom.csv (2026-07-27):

Item | Manufacturer Part Number | LCSC Part Number | Quantity | Specification | Procurement
Housing | GHR-02V-S | C50396276 | 2 | JST GH 2 circuit secure-lock | LCSC stock low at check; source from authorized distributor if unavailable
Crimp contact | SSHL-002T-P0.2 | C189897 | 4 | AWG30-26 tin contact | LCSC
Wire | UL1061 AWG28 twisted pair | DNI | 0.6m | Red/black 600mm; 0.214 ohm/m per conductor | Harness supplier
Strain relief | Heat-shrink + frame clips | DNI | As required | Fix cable at both boards and along stationary frame | Mechanical assembly

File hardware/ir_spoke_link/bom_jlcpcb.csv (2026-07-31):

Comment | Designator | Footprint | Manufacturer Part Number | LCSC Part Number | JLCPCB Library | Stock checked 2026-07-28 | Notes
PIN photodiode | D2 | VEMD10940F_SideView | VEMD10940FX01 | C7104273 | Extended | 4243 | Pad 2 is non-electrical reinforcement
Dual 10MHz RRIO op amp | U1 | SOT-23-8 | TLV9062IDDFR | C2867884 | Extended | 15173 | Selected over Basic LM358 for TIA bias and GBW
Push-pull comparator | U2 | SOT-353_SC-70-5 | TLV7011DCKR | C193688 | Extended | 2048 | 260ns typ and 4.2mV internal hysteresis
NPN low-side driver | Q1 | SOT-23 | S8050 J3Y | C2146 | Basic | 555818 | Remote LED current switch
JST GH right-angle secure-lock header | J3 | JST_GH_SM02B-GHS-TB_1x02-1MP_P1.25mm_Horizontal | SM02B-GHS-TB(LF)(SN) | C189893 | Extended | 30138 | Side-entry 1A 50V; captured PCB orientation 180 degrees
1k 1% | R2 | R_0402_1005Metric | 0402WGF1001TCE | C11702 | Basic | 1085756 | Base resistor
10k 1% | R3,R4,R7,R9 | R_0603_1608Metric | 0603WAF1002T5E | C25804 | Basic | 4568500 | In-stock Basic replacement for unavailable 0402
33k 1% | R5 | R_0402_1005Metric | 0402WGF3302TCE | C25779 | Basic | 1363300 | TIA feedback
16k 1% | R6 | R_0603_1608Metric | 0603WAF1602T5E | C4210 | Extended | 219179 | AC bias; corrected from mismatched C25770
560k 1% | R8 | R_0402_1005Metric | 0402WGF5603TCE | C132339 | Extended | 77707 | Gain feedback selected by tolerance sweep
1M 1% | R10 | R_0402_1005Metric | 0402WGF1004TCE | C26083 | Basic | 1084202 | Comparator positive feedback
100R 1% | R11 | R_0402_1005Metric | 0402WGF1000TCE | C25076 | Basic | 860298 | GPIO series
1uF 50V X5R | C1 | C_0603_1608Metric | CL10A105KB8NNNC | C15849 | Basic | 14931914 | VREF reservoir
120pF C0G | C2 | C_0402_1005Metric | CC0402JRNPO9BN121 | C106996 | Extended | 449666 | TIA stability/pole; corrected from 15pF C1548
1nF X7R | C3 | C_0402_1005Metric | 0402B102K500NT | C1523 | Basic | 5754284 | AC coupling
4.7pF C0G | C4 | C_0402_1005Metric | 0402CG4R7C500NT | C1569 | Extended | 871326 | Gain-stage pole
100nF X7R | C5,C6 | C_0402_1005Metric | CL05B104KO5NNNC | C1525 | Basic | 46835420 | Local decoupling
XIAO ESP32-S3 sockets | J1,J2 | PinSocket_1x07_P2.54mm_Vertical | DNI | DNI | DNI | N/A | Hand assemble or direct solder
940nm side-view IR LED | D1 | LED_0805_2012Metric | VSMB1940X01 | C3151600 | Extended | 629 | Panel emitter; optical geometry is not substitutable by a generic top-view LED
39R 1% 0.1W | R1 | R_0603_1608Metric | 0603WAF390JT5E | C23154 | Extended | 112431 | Panel-emitter current limit; exact Basic search returned no verified match
JST GH right-angle secure-lock header | J4 | JST_GH_SM02B-GHS-TB_1x02-1MP_P1.25mm_Horizontal | SM02B-GHS-TB(LF)(SN) | C189893 | Extended | 30138 | Panel-emitter side-entry cable connection; captured PCB orientation 0 degrees

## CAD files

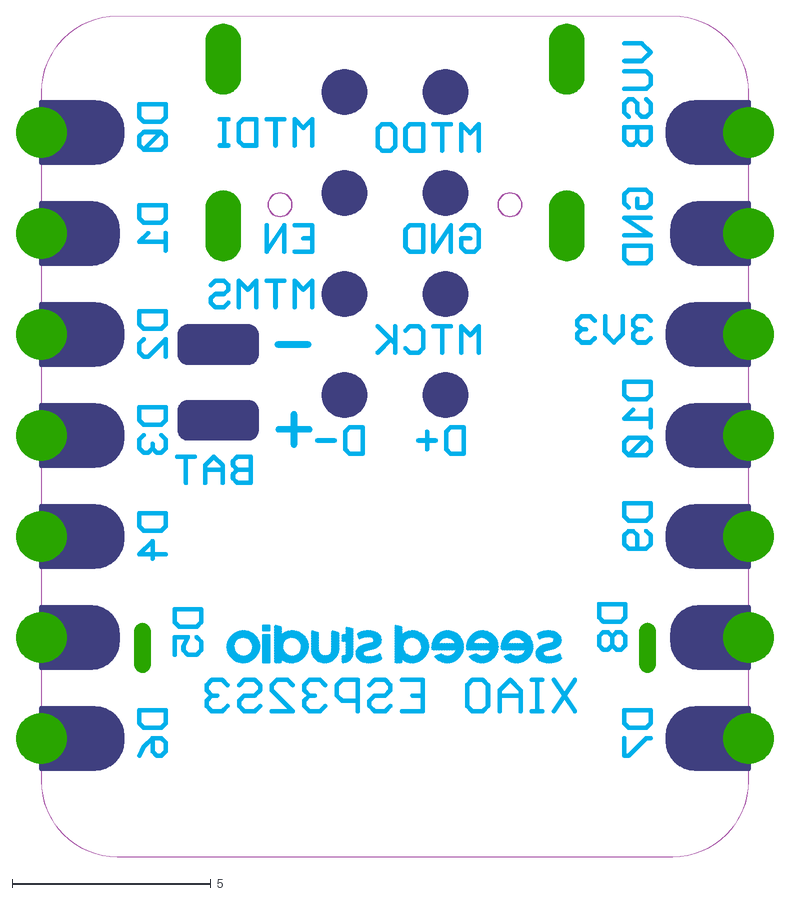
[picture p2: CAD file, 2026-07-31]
docs/datasheets/components/Seeed_XIAO_ESP32S3_v1.1_Dimensions.dxf
19.0 x 21.1

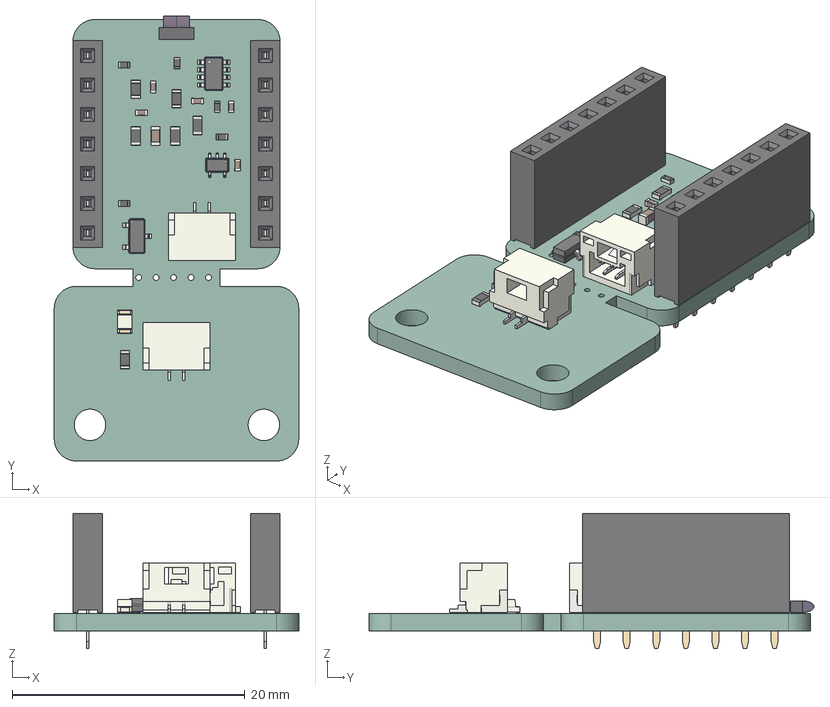
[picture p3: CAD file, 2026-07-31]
hardware/ir_spoke_link/ir_spoke_link.step
21.0 x 38.2 x 11.6 mm
R_0603_1608Metric x 6
SOT-353_SC-70-5
C_0402_1005Metric x 5
R_0402_1005Metric x 5
SOT-23-8
C_0603_1608Metric
JST_SM02B_GHS_TB x 2
LED_0805_2012Metric
package
daylight_filter_lens
cathode
anode
photodiode_die
PinSocket_1x07_P2.54mm_Vertical x 2
SOT-23
ir_C66B_PCB

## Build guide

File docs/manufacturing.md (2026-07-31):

# Manufacturing

## Ordered hardware release

| Field | Value |
|---|---|
| Hardware version | IR Spoke Sensor V0.1 |
| KiCad CAD revision | R4 |
| Layers | 2 |
| Material | FR-4 |
| Thickness | 1.6 mm |
| Copper | 1 oz |
| Panel size | 21 x 37.9 mm |
| Receiver finished size | 17.8 x 21.4 mm |
| Emitter finished size | 21 x 15 mm |
| Separation | One 7.5 x 1.5 mm conductive mouse-bite tab |
| Assembly side | Top |

The tab intentionally carries `3V3` and `LED_K` for pre-snap testing. Snapping
severs both traces. The two boards then reconnect through J3/J4 and the JST-GH
harness.

## Retrieve or reproduce V0.1

Download the immutable order assets from the
[Hardware V0.1 GitHub release](https://github.com/niklasdathe/IRBicycleWheelSpeedSensor/releases/tag/V0.1).
To reproduce them without changing the V0.2 development checkout, create a
separate worktree at the tag:

```powershell
git worktree add ..\IR-Spoke-Sensor-V0.1 V0.1
Set-Location ..\IR-Spoke-Sensor-V0.1
powershell -ExecutionPolicy Bypass -File hardware\export_jlc.ps1 -Revision V0.1
```

The exporter rejects a version that does not match the checked-out project.
It is also fail-closed: captured-layout restoration and footprint audit run
first, and no manufacturing files are accepted unless DRC reports 0 violations
and 0 unconnected pads.

Authoritative output:

`hardware/jlc_export/IR_Spoke_Sensor_V0.1_2L/`

| Upload/review artifact | File |
|---|---|
| Complete order/troubleshooting bundle | `IR_Spoke_Sensor_V0.1_2L_ORDER_PACKAGE.zip` |
| PCB fabrication | `IR_Spoke_Sensor_V0.1_2L_GERBER.zip` |
| BOM + CPL + order metadata | `IR_Spoke_Sensor_V0.1_2L_PCBA.zip` |
| Bill of materials | `IR_Spoke_Sensor_V0.1_2L_BOM.csv` |
| Component placement | `IR_Spoke_Sensor_V0.1_2L_CPL.csv` |
| Order parameters | `IR_Spoke_Sensor_V0.1_2L_ORDER.json` |
| DRC evidence | `IR_Spoke_Sensor_V0.1_2L_DRC.rpt` |
| Non-production courtyard reference | `IR_Spoke_Sensor_V0.1_2L_COURTYARD_REFERENCE.zip` |
| Release integrity | `IR_Spoke_Sensor_V0.1_2L_SHA256SUMS.txt` |
| Interactive placement guide | [`docs/interactive_bom.html`](interactive_bom.html) |

Do not upload the courtyard reference archive as production Gerbers.

## Assembly conventions

KiCad physical orientation and JLC placement rotation are separate. V0.1/R4 applies
CPL-only offsets without rotating footprints or changing tracks:

| Ref | Physical KiCad | CPL offset | Final JLC rotation |
|---|---:|---:|---:|
| U1 | 0° | 90° | 90° |
| U2 | 270° | 90° | 0° |
| J3 | 0° | 180° | 180° |
| J4 | 180° | 180° | 0° |
| D1 IR emitter | 0° | 180° | 180° |
| D2 photodiode | 0° | 0° | 0° |

The detailed polarity evidence is in
[JLC diode orientation](jlc_diode_orientation.md). Automated offsets do not
prove the third-party preview renderer; inspect the preview.

## JLC review checklist

- [ ] Upload the V0.1 Gerber archive and confirm a two-layer 1.6 mm board.
- [ ] Confirm the overall outline and four rounded corners on each finished
      board.
- [ ] Confirm the mouse-bite tab is a single breakaway and no V-groove exists.
- [ ] Request engineering review of the two intentional routed tab traces.
- [ ] Confirm both M2.5 emitter holes are excluded from assembly.
- [ ] Upload BOM/CPL and resolve every reference without substitutions.
- [ ] Visually verify D1/D2 polarity and U1/U2/J3/J4 orientation.
- [ ] Confirm J3/J4 are low side-entry JST-GH parts over their board cutouts.
- [ ] Keep front/back courtyards out of production layers.
- [ ] Record JLC DFM approval and preview screenshots as release evidence.

## Procurement and Konnect

`hardware/component_catalog.json` is the canonical part table.
`hardware/ir_spoke_link/bom_jlcpcb.csv` feeds the scoped Konnect SQLite cache
and the JLC export. Basic/extended classification and consolidation notes are
in [JLC basic-part review](../hardware/jlc_basic_consolidation.md).

For Konnect configuration and database limits, use
[Konnect and JLCPCB](konnect_jlcpcb.md).

## Release gate

V0.1 is the ordered hardware baseline. Preserve the `V0.1` Git tag and GitHub
release for troubleshooting. Manual JLC preview/DFM evidence and the physical
tests in [Bring-up and test](bringup.md) remain part of production validation.

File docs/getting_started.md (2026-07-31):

# Getting started

## Prerequisites

The checked scripts currently expect:

| Tool | Expected installation |
|---|---|
| Windows PowerShell | Windows host |
| KiCad | `C:\Program Files\KiCad\10.0` |
| Python | `py -3.14` |
| ngspice | on `PATH`, or `%USERPROFILE%\Tools\ngspice\46\bin\ngspice_con.exe` |

Run commands from the project root.

## Open the authoritative KiCad project

```powershell
.\Open-IR-Spoke-Sensor.cmd
```

The launcher verifies that the captured project is internally consistent, then
opens `hardware/ir_spoke_link/ir_spoke_link.kicad_pro`. Do not open a copied
or generated export as the design source.

## Explore and tune the live model

```powershell
py -3.14 simulation\local_server.py
```

Open `http://127.0.0.1:8765/`. Changing a control runs the same Python transient
used by batch tests. Reset reloads `config/system.json`; code export runs the
selected values through the simulation before returning a C header.

The transient always contains a complete spoke blockage and exposes optical,
TIA, band-pass, comparator, RMT and power traces.

## Run complete verification

```powershell
powershell -ExecutionPolicy Bypass -File tests\run_all.ps1
```

The command regenerates linked constants and topology, runs Python and ngspice,
executes the tolerance sweep and unit/API tests, validates the native KiCad
netlist and footprints, exports the schematic PDF, restores the captured PCB,
then runs ERC and DRC.

Success means every command returns zero and the final DRC reports 0 violations
and 0 unconnected pads. The current ERC has 0 errors and three documented
TLV9062 library-sync warnings. Generated evidence appears under `build/`.

## Read the result

| Question | Location |
|---|---|
| Which requirements passed automatically? | `requirements/verification_matrix.md` |
| Which physical tests remain? | `TODO.md` |
| Which defaults produced the result? | `config/system.json` |
| Which waveform assumptions were used? | `simulation/README.md` |
| Which datasheet values support them? | `docs/datasheet_values.json` |
| Is the captured routing unchanged? | `hardware/ir_spoke_link/layout_manifest.json` |

For edits, continue with [Development workflow](development.md). For ordering,
continue with [Manufacturing](manufacturing.md).

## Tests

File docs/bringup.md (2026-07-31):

# Bring-up and test

## Equipment

- current-limited 5 V USB supply with current logging;
- oscilloscope with short ground spring;
- optical fixture with adjustable emitter/receiver spacing and alignment;
- rotating wheel or controlled spoke target;
- sunlight or calibrated high-irradiance source;
- optional terminated CAN bus and official XIAO CAN expansion.

Do not probe the photodiode summing node `PD_ANODE`; probe capacitance changes
the TIA response.

## Testpoints

| TP | Net | Expected observation |
|---|---|---|
| TP1 | GND | probe reference |
| TP2 | +3V3 | startup and transient droop |
| TP3 | VREF | approximately 1.65 V after startup |
| TP4 | TX_CARRIER_GPIO1 | selected carrier, 50% duty |
| TP5 | TIA_OUT | photodiode current around VREF with headroom |
| TP6 | BANDPASS | AC carrier with DC/slow ambient removed |
| TP7 | COMP_OUT | restored digital carrier; quiet during blockage |
| TP8 | RX_RMT_GPIO2 | comparator signal after GPIO isolation |

## Sequence

### 1. Unpowered inspection

- Verify D1 anode/cathode and D2 photodiode polarity against the schematic and
  datasheets.
- Check the conductive tab, mouse bites, harness pin 1/2 continuity and absence
  of shorts.
- Confirm connector and XIAO header alignment before stacking.

### 2. Current-limited power-up

- Start without CAN and with a conservative current limit.
- Record cold-start, idle and carrier-on current.
- Verify TP2 and TP3 before enabling optical operation.
- Compare current and rail droop with the power traces in the local simulator.

### 3. Electrical signal correlation

- Set the default configuration.
- Capture TP4-TP8 in one acquisition with a complete blockage.
- Export the local-simulator waveform for the same carrier, speed, spoke width
  and distance.
- Compare frequency, duty, DC headroom, band-pass amplitude, hysteresis
  transitions and blockage width.
- Store measured deltas and update `config/system.json` only from repeatable
  data.

### 4. Optical margin

Sweep at least:

- 25 kHz, 38 kHz and 50 kHz;
- minimum, nominal and maximum mounting distance;
- alignment and vibration extremes;
- shade, direct sunlight and changing shadows;
- clean, dirty and wet optical surfaces;
- slow rotation through the 80 km/h stress condition.

For each point, record TP5/TP6 amplitude, false events, missed events and RMT
blockage-width margin.

### 5. Adaptive algorithm

- Run wheels or targets with different spoke counts across 16-48.
- Record inferred count, confidence convergence time and LUT residuals.
- Introduce bounded speed changes and individual interval irregularities.
- Verify continuous recovery after an outlier or temporary blockage.
- Document the expected ambiguity for a perfectly uniform spoke pattern.

### 6. Power and optional CAN

- Capture cold-start and Wi-Fi TX peak current.
- Repeat with coincident carrier, Wi-Fi and CPU activity.
- Stack the official CAN expansion, check D0/D1 versus D6-D10 pin separation,
  then repeat with a terminated 500 kbit/s bus and dominant traffic.
- Verify regulator temperature, 3.3 V droop and CAN error counters.

## Acceptance evidence

Record raw waveforms, configuration JSON, firmware revision, board revision,
fixture geometry, environmental condition and pass/fail result. Map each record
to the relevant test ID in
[the verification matrix](../requirements/verification_matrix.md).

The current open physical gates are maintained in [TODO.md](../TODO.md).
Successful bench correlation should replace assumptions in the model; it must
not merely be noted in prose.

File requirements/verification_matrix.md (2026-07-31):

# Verification matrix

| Test ID | Method | Automated now | Evidence / status |
|---|---|---:|---|
| T-SIM-001 | Python transient simulation counts valid blockage windows | Yes | `tests/test_system.py` |
| T-CALC-001 | 80 km/h geometry calculation against capture limits | Yes | `tests/test_system.py` |
| T-CFG-001 | Runtime carrier boundary/default and wavelength/duty checks | Yes | `tests/test_system.py` |
| T-CALC-002 | Installed LED resistor/current calculation | Yes | `tests/test_system.py` |
| T-HW-004 | Harness BOM, connector rating and loop-drop check | Yes | `hardware/cable_bom.csv`, `tests/test_system.py` |
| T-HW-001 | Schematic/BOM architecture inspection | Yes | `tests/test_system.py` |
| T-CALC-003 | RC response calculation at 25, 38 and 50 kHz | Yes | `tests/test_system.py` |
| T-SIM-002 | Comparator and RMT-demodulated waveform assertions | Yes | `tests/test_system.py` |
| T-SIM-003 | TIA headroom assertion | Yes | `tests/test_system.py` |
| T-SIM-004 | 10,000-case tolerance/environment sweep | Yes | `simulation/ir_spoke_sim.py`, `tests/run_all.ps1` |
| T-SW-001 | Generated ESP-IDF source inspection | Yes | `tests/test_system.py` |
| T-ANALYSIS-001 | RMT/MCPWM decision record | Yes | `docs/architecture_decision.md` |
| T-GEN-001 | Regenerate header/SPICE and compare working tree | Yes | `tests/run_all.ps1` |
| T-SW-002 | Portable C99 module/interface and no-heap audit | Yes | `tests/test_system.py` |
| T-SW-003 | Pattern-inference source/host-model review | Partial | C module implemented; target compiler not installed |
| T-SW-004 | Source-level LUT/adaptation assertions | Yes | `tests/test_system.py` |
| T-SW-005 | Official ESP-IDF RMT API and runtime-field relationship inspection | Yes | `tests/test_system.py` |
| T-API-001 | Local API defaults, simulation and generated C header | Yes | `tests/test_local_server.py` |
| T-SIM-005 | Short/long transient centred-blockage and extended-trace assertions | Yes | `tests/test_system.py` |
| T-PWR-001 | Datasheet-based average/peak power and transient-trace assertions | Yes | `simulation/ir_spoke_sim.py`, `tests/test_system.py` |
| T-CAN-001 | Official XIAO CAN pin-map, SPI limit and optional worst-case power assertions | Yes | `docs/datasheet_values.json`, `tests/test_system.py` |
| T-SW-006 | Portable CAN publisher and isolated ESP-IDF MCP2515/SPI adapter audit | Yes | `firmware/components/ir_spoke_core/ir_spoke_can.c`, `firmware/main/ir_spoke_can_mcp2515_adapter.c` |
| T-NET-001 | KiCad-native XML netlist, PCB pads and SPICE SHA against canonical manifest | Yes | `tools/validate_kicad_netlist.py`, `hardware/footprint_audit.py`, `simulation/connectivity_guard.py` |
| T-DBG-001 | Required testpoint net/pad and no-PD-summing-node-probe audit | Yes | `hardware/connectivity.json`, `hardware/footprint_audit.py`, `tests/test_system.py` |
| T-KONNECT-001 | SQLite integrity/schema/row-scope test | Yes | `tests/test_system.py`, `hardware/konnect_database_manifest.json` |
| T-PCB-001 | KiCad Python footprint audit | Yes | `hardware/footprint_audit.py` |
| T-PCB-002 | KiCad DRC | Yes | Combined receiver/emitter panel: 0 findings / 0 open pads |
| T-PCB-003 | Fail-closed export script | Yes | `hardware/export_jlc.ps1` |
| T-PCB-004 | Main-board routed-state gate | Yes | `hardware/ir_spoke_link/drc.rpt`; 0 findings, 0 unconnected pads, fabrication-ready true |
| T-PCB-005 | Captured layout, trace/via/angle/zone/courtyard audit | Yes | `hardware/ir_spoke_link/layout_manifest.json`, `hardware/footprint_audit.py` |
| T-PCB-006 | Exact receiver/transmitter dimensions, rounded-corner outline, single conductive tab, net ties, mouse-bites, emitter parts and M2.5-hole audit | Yes | `hardware/footprint_audit.py` |
| T-PCB-007 | Right-angle JST-GH MPN/LCSC/footprint/pin-map, courtyard and 3D-model audit with protected routing signature | Yes | `hardware/component_catalog.json`, `hardware/connectivity.json`, `hardware/footprint_audit.py`, `hardware/ir_spoke_link/layout_integrity.py` |
| T-PCB-008 | KiCad editor-layer preference plus separate front/back courtyard Gerber export | Yes | `hardware/ir_spoke_link/ir_spoke_link.kicad_prl`, `hardware/export_jlc.ps1` |
| T-DOC-001 | Datasheet extraction manifest cross-check | Yes | `docs/datasheet_values.json`, `tests/test_system.py` |
| T-DOC-002 | Technical HTML parses and covers signal chain, algorithm and open gates | Yes | `local_simulator/technical.html`, `tests/test_system.py` |
| T-DOC-003 | Daylight-filter datasheet field and layered ambient-rejection rationale | Yes | `docs/datasheet_values.json`, `docs/debug_and_threshold.md`, `tests/test_system.py` |
| T-DOC-004 | Task-guide structure, visible maturity/release gates, authoritative-source map, local Markdown links and documentation-index coverage | Yes | `README.md`, `docs/README.md`, `tools/audit_project.py`, `tests/test_system.py` |
| T-DOC-005 | KiCad-sourced InteractiveHtmlBom output, pinned generator, source/output hashes, procurement fields and live-watch entry point | Yes | `docs/interactive_bom.html`, `docs/interactive_bom.json`, `tools/interactive_bom.py`, `tests/test_system.py` |
| T-PHYS-001 | Environmental bench/road test | No | Required before production; see `TODO.md` |

The combined receiver/emitter panel passes KiCad DRC with the captured physical
footprint orientations. U1/U2/J3/J4 corrections exist only in the JLC
CPL generator; D1 uses the required 180-degree LCSC/KiCad convention correction
and D2 uses zero degrees. JLC assembly-preview approval,
bench correlation and environmental validation remain required before release.

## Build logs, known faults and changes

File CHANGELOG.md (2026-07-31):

# Changelog

Hardware and software are versioned independently. Hardware entries describe
manufactured PCB states; software entries describe firmware behavior.

## Hardware

### V0.2 — Unreleased

Changes relative to the ordered V0.1 baseline:

- Development line opened; no electrical, mechanical, placement or routing
  change has been made yet.
- Hardware changes must be recorded here before a future V0.2 release.

### V0.1 — 2026-07-31

Ordered baseline, corresponding to KiCad CAD revision R4 and Git tag `V0.1`.

- Two-layer 17.8 x 21.4 mm XIAO receiver carrier.
- Breakaway 940 nm emitter board with two M2.5 mounting holes.
- Conductive mouse-bite tab for pre-snap functional testing.
- Discrete TLV9062/TLV7011 receiver and RMT-based ESP32-S3 interface.
- Right-angle JST-GH remote-emitter connection and optional XIAO CAN board.
- JLCPCB Gerber, BOM, CPL, order metadata and checksum package released.

## Software

### SW-V0.1.0 — Unreleased

- Portable adaptive spoke-learning core and ESP-IDF RMT integration are under
  development; no software release is implied by hardware V0.1.

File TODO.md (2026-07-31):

# Open validation gates

- [ ] Select and add explicit hardware, software and documentation licenses
  before describing the repository as reusable open-source hardware.
- [ ] Resolve the three KiCad ERC `lib_symbol_mismatch` warnings by updating
  the embedded TLV9062 units from the KiCad 10 library without changing pins,
  nets or schematic layout.
- [ ] Compile and hardware-in-loop test the RMT and MCP2515 adapters with the
  selected ESP-IDF release.
- [ ] Stack the official XIAO CAN expansion with the intended headers; verify
  clearance and 500 kbit/s traffic on a terminated bus.
- [ ] Resolve the two optional PCB presentation items after the next manual
  routing edit: Edge.Cuts dimension-text placement and backside CMP/TP2
  silkscreen overlap.
- [ ] Measure photocurrent, noise and detection margin across sunlight,
  alignment, vibration, dirt, water, minimum/default/maximum carrier and
  distance; update `config/system.json`.
- [ ] Correlate TP2–TP8 bench waveforms with Python and ngspice.
- [ ] Measure cold-start, Wi-Fi TX and coincident Wi-Fi/LED/CAN rail current
  and droop; update source impedance and inrush parameters.
- [ ] Re-run simulation and compile firmware with the measured parameter set.
- [ ] Review the R4 Gerber/BOM/CPL in JLCPCB, obtain DFM approval for the
  conductive mouse-bite tab and confirm all assembly rotations visually.

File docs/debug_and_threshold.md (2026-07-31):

# Debug nodes and threshold policy

| Test point | Net | Correlated transient | Use |
|---|---|---|---|
| TP1 | GND | reference | probe ground |
| TP2 | +3V3 | supply/current setup | rail droop and startup |
| TP3 | VREF | threshold reference | 1.65 V startup/noise |
| TP4 | TX_CARRIER_GPIO1 | `carrier` | RMT TX and base drive |
| TP5 | TIA_OUT | `tia_v` | ambient headroom and optical current |
| TP6 | BANDPASS | `bandpass_v` | carrier amplitude and filter response |
| TP7 | COMP_OUT | `comparator` | analog decision |
| TP8 | RX_RMT_GPIO2 | RMT input | GPIO isolation and hardware demodulation input |

The 1 mm pads are on the main PCB underside and excluded from BOM and
placement output. Do not probe `PD_ANODE`: ordinary probe capacitance changes
the TIA noise gain and bandwidth. Use a short ground spring at TP5/TP6.

## Potentiometer decision

A threshold potentiometer is not fitted. Distance changes the AC carrier
amplitude; shifting the comparator center away from VREF does not directly
correct that amplitude and reduces asymmetric headroom. A trimmer also adds
area, vibration sensitivity, contact drift and manual calibration, conflicting
with continuous adaptive operation.

The installed 10 kOhm input / 1 MOhm feedback network produces approximately
37.2 mV total typical hysteresis including TLV7011 internal hysteresis. Bench
work should first measure TP5 and TP6 across distance, sunlight and alignment.
If decision margin is insufficient, change fixed gain/hysteresis values and
regenerate simulation/firmware. An optional DNP trimmer footprint should only
be added after those measurements show a need; it is not a production control.

The VEMD10940FX01 has an optical daylight-blocking filter matched to
830-950 nm emitters. It is not a sunlight eliminator: sunlight still contains
940 nm energy. Reverse bias preserves speed; TIA headroom handles DC ambient,
the AC band-pass rejects DC/slow changes, and carrier-loss timing supplies the
remaining discrimination. Direct-sun testing remains mandatory.

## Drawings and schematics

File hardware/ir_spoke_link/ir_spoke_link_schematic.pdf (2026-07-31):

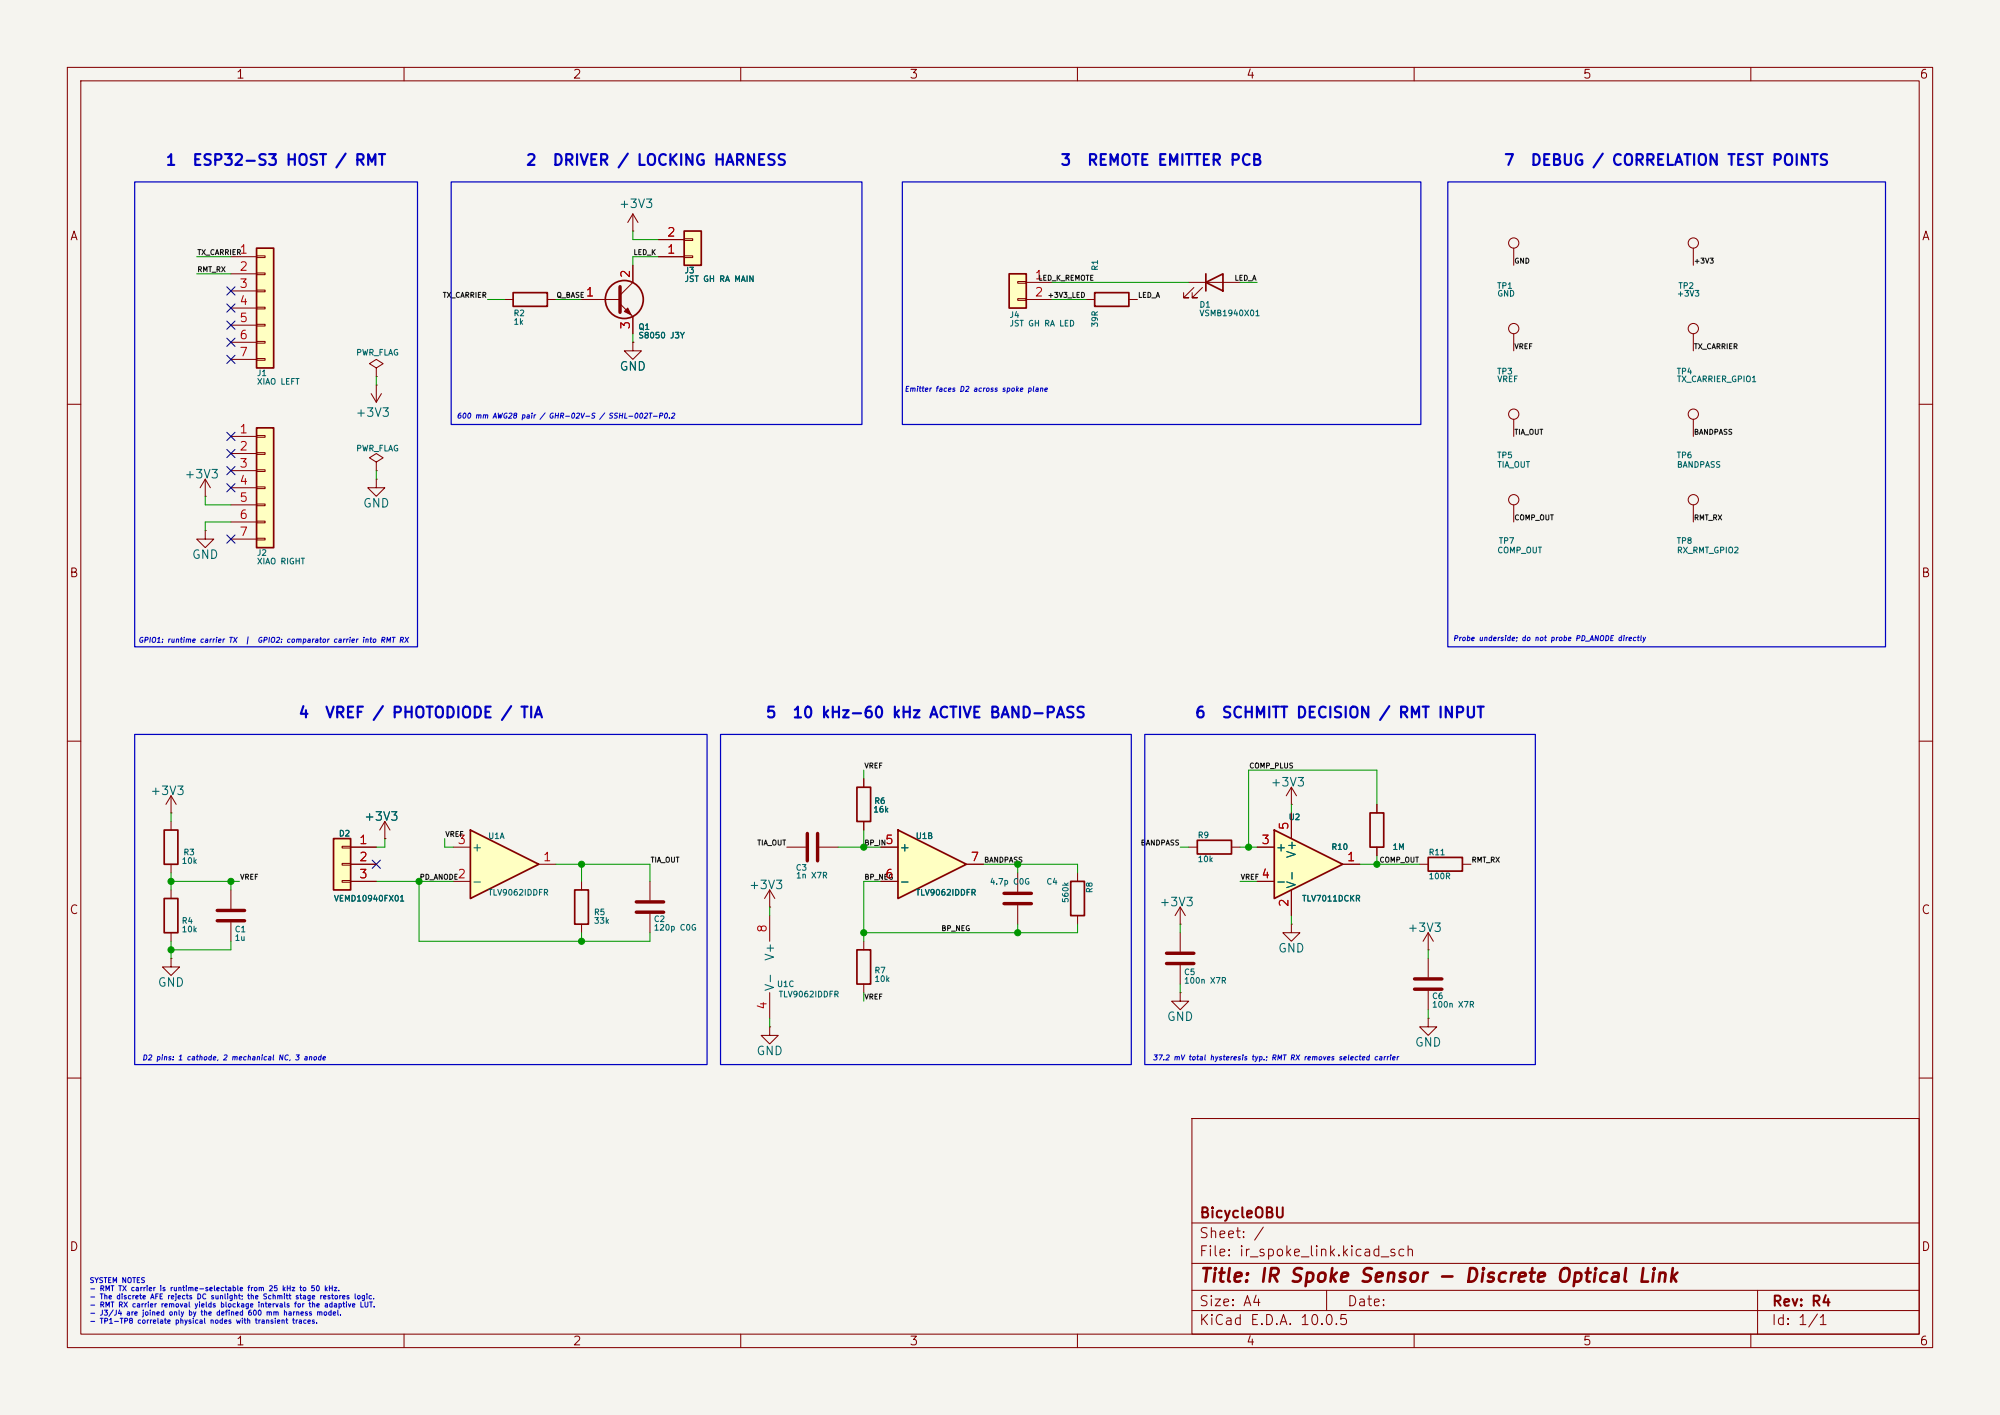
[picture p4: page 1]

JST GH RA MAIN 1

Emitter faces D2 across spoke plane

GPIO1: runtime carrier TX | GPIO2: comparator carrier into RMT RX

37.2 mV total hysteresis typ.; RMT RX removes selected carrier

Sheet: /
File: ir_spoke_link.kicad_sch
Title: IR Spoke Sensor - Discrete Optical Link

SYSTEM NOTES - RMT TX carrier is runtime-selectable from 25 kHz to 50 kHz. - The discrete AFE rejects DC sunlight; the Schmitt stage restores logic. - RMT RX carrier removal yields blockage intervals for the adaptive LUT. - J3/J4 are joined only by the defined 600 mm harness model. - TP1-TP8 correlate physical nodes with transient traces.

Size: A4 | Rev: R4
KiCad E.D.A. 10.0.5 | Id: 1/1

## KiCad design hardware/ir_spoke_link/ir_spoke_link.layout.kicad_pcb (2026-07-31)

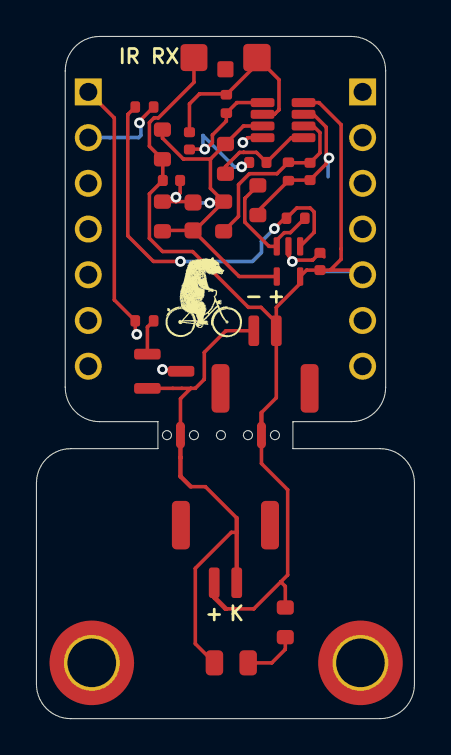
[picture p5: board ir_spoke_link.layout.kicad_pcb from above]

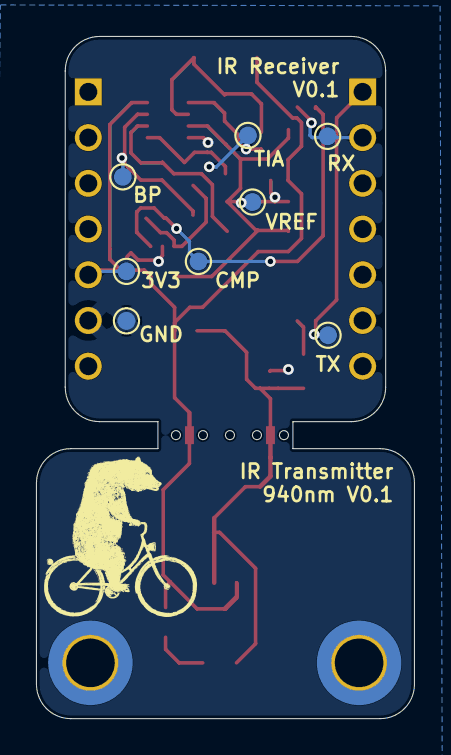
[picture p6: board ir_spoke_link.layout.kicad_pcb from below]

Board: 2 copper layers, 21.0 x 37.9 mm, 43 parts (8 on the bottom side), 17 nets.

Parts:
C1: 1u; C_0603_1608Metric
C2: 120p; C_0402_1005Metric
C3: 1n; C_0402_1005Metric
C4: 4.7p; C_0402_1005Metric
C5, C6: 100n; C_0402_1005Metric
D1: VSMB1940X01; LED_0805_2012Metric
D2: VEMD10940FX01; VEMD10940F_SideView
J1: XIAO_LEFT; PinSocket_1x07_P2.54mm_Vertical
J2: XIAO_RIGHT; PinSocket_1x07_P2.54mm_Vertical
J3: TX CABLE; JST_GH_SM02B-GHS-TB_1x02-1MP_P1.25mm_Horizontal
J4: JST GH LED; JST_GH_SM02B-GHS-TB_1x02-1MP_P1.25mm_Horizontal
MB1, MB2, MB3, MB4, MB5: BREAKAWAY_NPTH_0.5; Breakaway_MouseBite_0.5mm
MH1, MH2: MountingHole_2.7mm_M2.5_DIN965_Pad_TopBottom
NT1, NT2: TEMP_BREAKAWAY_LINK; NetTie-2_SMD_Pad0.5mm
Q1: S8050; SOT-23
R1: 39R; R_0603_1608Metric
R2: 1k; R_0402_1005Metric
R3, R4, R7, R9: 10k; R_0603_1608Metric
R5: 33k; R_0402_1005Metric
R6: 16k; R_0603_1608Metric
R8: 560k; R_0402_1005Metric
R10: 1M; R_0402_1005Metric
R11: 100R; R_0402_1005Metric
TP1: GND; TestPoint_Pad_D1.0mm
TP2: +3V3; TestPoint_Pad_D1.0mm
TP3: VREF; TestPoint_Pad_D1.0mm
TP4: TX_CARRIER_GPIO1; TestPoint_Pad_D1.0mm
TP5: TIA_OUT; TestPoint_Pad_D1.0mm
TP6: BANDPASS; TestPoint_Pad_D1.0mm
TP7: COMP_OUT; TestPoint_Pad_D1.0mm
TP8: RX_RMT_GPIO2; TestPoint_Pad_D1.0mm
U1: TLV9062IDDFR; SOT-23-8
U2: TLV7011DCKR; SOT-353_SC-70-5

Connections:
+3V3: C5.1, C6.1, D2.1, J2.5, J3.2, NT2.2, R3.1, TP2.1, U1.8, U2.5
+3V3_LED: J4.2, NT2.1, R1.1
BANDPASS: C4.1, R8.1, R9.1, TP6.1, U1.7
BP_IN: C3.2, R6.1, U1.5
BP_NEG: C4.2, R7.1, R8.2, U1.6
COMP_OUT: R10.1, R11.1, TP7.1, U2.1
COMP_PLUS: R9.2, R10.2, U2.3
GND: C1.2, C5.2, C6.2, J2.6, Q1.3, R4.2, TP1.1, U1.4, U2.2
LED_A: D1.2, R1.2
LED_K_REMOTE: D1.1, J4.1, NT1.1
LED_K_SWITCHED: J3.1, NT1.2, Q1.2
PD_ANODE: C2.2, D2.3, R5.2, U1.2
Q_BASE: Q1.1, R2.2
RX_RMT_GPIO2: J1.2, R11.2, TP8.1
TIA_OUT: C2.1, C3.1, R5.1, TP5.1, U1.1
TX_CARRIER_GPIO1: J1.1, R2.1, TP4.1
VREF: C1.1, R3.2, R4.1, R6.2, R7.2, TP3.1, U1.3, U2.4

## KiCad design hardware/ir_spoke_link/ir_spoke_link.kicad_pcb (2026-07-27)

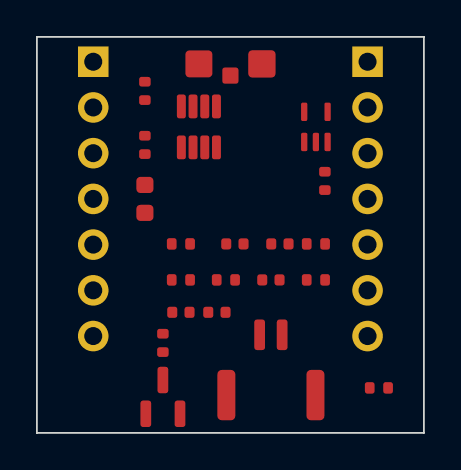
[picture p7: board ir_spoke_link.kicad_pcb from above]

Board: 2 copper layers, 21.5 x 22.0 mm, 23 parts (0 on the bottom side), 14 nets, no tracks yet.

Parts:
C1: 1u; C_0603_1608Metric
C2: 120p; C_0402_1005Metric
C3: 1n; C_0402_1005Metric
C4: 4.7p; C_0402_1005Metric
C5, C6: 100n; C_0402_1005Metric
D2: VEMD10940FX01; VEMD10940F_SideView
J1: XIAO_LEFT; PinSocket_1x07_P2.54mm_Vertical
J2: XIAO_RIGHT; PinSocket_1x07_P2.54mm_Vertical
J3: TX CABLE; JST_GH_BM02B-GHS-TBT_1x02-1MP_P1.25mm_Vertical
Q1: S8050; SOT-23
R2: 1k; R_0402_1005Metric
R3, R4, R7, R9: 10k; R_0402_1005Metric
R5: 33k; R_0402_1005Metric
R6: 16k; R_0402_1005Metric
R8: 560k; R_0402_1005Metric
R10: 1M; R_0402_1005Metric
R11: 100R; R_0402_1005Metric
U1: TLV9062IDDFR; SOT-23-8
U2: TLV7011DCKR; SOT-353_SC-70-5

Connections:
+3V3: C5.1, C6.1, D2.1, J2.5, R3.1, U1.8, U2.5
BANDPASS: C4.1, R8.1, R9.1, U1.7
BP_IN: C3.2, R6.1, U1.5
BP_NEG: C4.2, R7.1, R8.2, U1.6
COMP_OUT: R10.1, R11.1, U2.1
COMP_PLUS: R9.2, R10.2, U2.3
GND: C1.2, C5.2, C6.2, J2.6, Q1.3, R4.2, U1.4, U2.2
LED_K_SWITCHED: J3.2, Q1.2
PD_ANODE: C2.2, D2.3, R5.2, U1.2
Q_BASE: Q1.1, R2.2
RX_RMT_GPIO2: J1.2, R11.2
TIA_OUT: C2.1, C3.1, R5.1, U1.1
TX_CARRIER_GPIO1: J1.1, R2.1
VREF: C1.1, R3.2, R4.1, R6.2, R7.2, U1.3, U2.4

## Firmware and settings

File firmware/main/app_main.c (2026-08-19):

#include "esp_check.h"
#include "esp_log.h"
#include "ir_spoke_ble_csc.h"
#include "ir_spoke_can.h"
#include "ir_spoke_can_mcp2515_adapter.h"
#include "ir_spoke_config.h"
#include "ir_spoke_debug.h"
#include "ir_spoke_link_monitor.h"
#include "ir_spoke_pipeline.h"
#include "ir_spoke_rmt_adapter.h"

static ir_spoke_runtime_config_t runtime_config;
static ir_spoke_pipeline_t pipeline;
static ir_spoke_can_publisher_t can_publisher;

void app_main(void) {
    const esp_err_t debug_result = ir_spoke_debug_init();
    if (debug_result != ESP_OK) {
        ESP_LOGW("ir_spoke", "debug initialization failed: %s",
                 esp_err_to_name(debug_result));
    }

    ir_spoke_debug_event(IR_SPOKE_DEBUG_STARTUP,
                         "application starting");
    ir_spoke_config_defaults(&runtime_config);
    /* Application code may change carrier_hz before start, within the
       generated analog-compatible bounds. */
    ir_spoke_debug_event(
        IR_SPOKE_DEBUG_STARTUP,
        "config tx_gpio=%ld rx_gpio=%ld carrier=%luHz demod=%luHz "
        "rmt=%luHz glitch=%luus pulse=%lu..%luus link_loss=%luus",
        (long)runtime_config.tx_gpio,
        (long)runtime_config.rx_gpio,
        (unsigned long)runtime_config.carrier_hz,
        (unsigned long)ir_spoke_config_rx_demod_hz(&runtime_config),
        (unsigned long)runtime_config.rmt_resolution_hz,
        (unsigned long)runtime_config.rx_glitch_filter_us,
        (unsigned long)runtime_config.blockage_min_us,
        (unsigned long)runtime_config.blockage_max_us,
        (unsigned long)runtime_config.link_loss_us);

    ir_spoke_pipeline_init(&pipeline);
    ir_spoke_debug_event(IR_SPOKE_DEBUG_STARTUP,
                         "pulse detector and spoke estimator initialized");

    const int ble_result = ir_spoke_ble_csc_start();
    if (ble_result != 0) {
        ir_spoke_debug_event(IR_SPOKE_DEBUG_ERROR,
                             "BLE CSC start failed rc=%d", ble_result);
    }
    ESP_ERROR_CHECK(ble_result == 0 ? ESP_OK : ESP_FAIL);

    if (IR_SPOKE_CAN_ENABLED_DEFAULT) {
        ir_spoke_can_transport_t transport = {0};
        ir_spoke_debug_event(IR_SPOKE_DEBUG_CAN,
                             "optional MCP2515 CAN telemetry requested");
        const int can_result = ir_spoke_can_mcp2515_start(&transport);
        if (can_result != 0) {
            ir_spoke_debug_event(IR_SPOKE_DEBUG_ERROR,
                                 "MCP2515 start failed rc=%d", can_result);
        }
        ESP_ERROR_CHECK(can_result == 0 ? ESP_OK : ESP_FAIL);
        ir_spoke_can_publisher_init(
            &can_publisher, transport,
            IR_SPOKE_CAN_TELEMETRY_BASE_ID, true);
        ir_spoke_rmt_set_can_publisher(&can_publisher);
        ESP_LOGI("ir_spoke", "optional MCP2515 CAN telemetry enabled");
        ir_spoke_debug_event(IR_SPOKE_DEBUG_CAN,
                             "CAN telemetry publisher ready base_id=0x%03x",
                             IR_SPOKE_CAN_TELEMETRY_BASE_ID);
    } else {
        ir_spoke_debug_event(IR_SPOKE_DEBUG_CAN,
                             "optional MCP2515 CAN telemetry disabled");
    }

    const int rmt_result = ir_spoke_rmt_start(&runtime_config, &pipeline);
    if (rmt_result != 0) {
        ir_spoke_debug_event(IR_SPOKE_DEBUG_ERROR,
                             "RMT start failed rc=%d", rmt_result);
    }
    ESP_ERROR_CHECK(rmt_result == 0 ? ESP_OK : ESP_FAIL);

    const esp_err_t link_result =
        ir_spoke_link_monitor_start(&runtime_config);
    if (link_result != ESP_OK) {
        ir_spoke_debug_event(
            IR_SPOKE_DEBUG_ERROR,
            "optical carrier link monitor unavailable: %s",
            esp_err_to_name(link_result));
    }

    ir_spoke_debug_event(IR_SPOKE_DEBUG_STARTUP,
                         "startup complete; sensor is running");
}

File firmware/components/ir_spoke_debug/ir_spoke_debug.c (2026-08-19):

#include "ir_spoke_debug.h"

#include <stdarg.h>
#include <stdbool.h>
#include <stdio.h>

#include "driver/gpio.h"
#include "esp_log.h"
#include "esp_timer.h"
#include "sdkconfig.h"

#define DEBUG_TAG "ir_debug"
#define DEBUG_MESSAGE_SIZE 224
#define LED_STATUS_TICK_US 100000ULL

static bool initialized;
static volatile ir_spoke_link_state_t link_state = IR_SPOKE_LINK_UNKNOWN;
static int64_t last_link_report_us;

#if defined(CONFIG_IR_SPOKE_DEBUG_ENABLE) && defined(CONFIG_IR_SPOKE_DEBUG_LED)
static esp_timer_handle_t led_off_timer;
static esp_timer_handle_t led_status_timer;
static volatile bool led_event_active;
static volatile uint32_t led_status_tick;

static int led_level(bool on) {
#ifdef CONFIG_IR_SPOKE_DEBUG_LED_ACTIVE_LOW
    return on ? 0 : 1;
#else
    return on ? 1 : 0;
#endif
}

static void set_led(bool on) {
    gpio_set_level((gpio_num_t)CONFIG_IR_SPOKE_DEBUG_LED_GPIO,
                   led_level(on));
}

static bool link_status_led_on(void) {
#ifdef CONFIG_IR_SPOKE_DEBUG_LED_LINK_STATUS
    switch (link_state) {
        case IR_SPOKE_LINK_UP:
            return true;
        case IR_SPOKE_LINK_DOWN:
            return (led_status_tick % 10u) == 0u;
        case IR_SPOKE_LINK_UNKNOWN:
        default:
            return (led_status_tick % 4u) < 2u;
    }
#else
    return false;
#endif
}

static void apply_led_base_state(void) {
    if (!initialized || led_event_active) return;
    set_led(link_status_led_on());
}

static void led_off(void *argument) {
    (void)argument;
    led_event_active = false;
    apply_led_base_state();
}

static void led_status_tick_callback(void *argument) {
    (void)argument;
    ++led_status_tick;
    apply_led_base_state();
}
#endif

static const char *event_name(ir_spoke_debug_event_t event) {
    switch (event) {
        case IR_SPOKE_DEBUG_STARTUP: return "startup";
        case IR_SPOKE_DEBUG_RMT: return "rmt";
        case IR_SPOKE_DEBUG_RMT_CAPTURE: return "rmt-capture";
        case IR_SPOKE_DEBUG_LINK: return "link";
        case IR_SPOKE_DEBUG_PULSE_ACCEPTED: return "pulse-ok";
        case IR_SPOKE_DEBUG_PULSE_REJECTED: return "pulse-reject";
        case IR_SPOKE_DEBUG_ESTIMATOR: return "estimator";
        case IR_SPOKE_DEBUG_REVOLUTION: return "revolution";
        case IR_SPOKE_DEBUG_BLE: return "ble";
        case IR_SPOKE_DEBUG_BLE_NOTIFY: return "ble-notify";
        case IR_SPOKE_DEBUG_CAN: return "can";
        case IR_SPOKE_DEBUG_CAN_TX: return "can-tx";
        case IR_SPOKE_DEBUG_ERROR: return "error";
        default: return "unknown";
    }
}

static bool serial_enabled(ir_spoke_debug_event_t event) {
#if defined(CONFIG_IR_SPOKE_DEBUG_ENABLE) && defined(CONFIG_IR_SPOKE_DEBUG_SERIAL)
    switch (event) {
#ifdef CONFIG_IR_SPOKE_DEBUG_SERIAL_STARTUP
        case IR_SPOKE_DEBUG_STARTUP: return true;
#endif
#ifdef CONFIG_IR_SPOKE_DEBUG_SERIAL_RMT
        case IR_SPOKE_DEBUG_RMT: return true;
#endif
#ifdef CONFIG_IR_SPOKE_DEBUG_SERIAL_RMT_CAPTURES
        case IR_SPOKE_DEBUG_RMT_CAPTURE: return true;
#endif
#ifdef CONFIG_IR_SPOKE_DEBUG_SERIAL_LINK
        case IR_SPOKE_DEBUG_LINK: return true;
#endif
#ifdef CONFIG_IR_SPOKE_DEBUG_SERIAL_PULSE_ACCEPTED
        case IR_SPOKE_DEBUG_PULSE_ACCEPTED: return true;
#endif
#ifdef CONFIG_IR_SPOKE_DEBUG_SERIAL_PULSE_REJECTED
        case IR_SPOKE_DEBUG_PULSE_REJECTED: return true;
#endif
#ifdef CONFIG_IR_SPOKE_DEBUG_SERIAL_ESTIMATOR
        case IR_SPOKE_DEBUG_ESTIMATOR: return true;
#endif
#ifdef CONFIG_IR_SPOKE_DEBUG_SERIAL_REVOLUTION
        case IR_SPOKE_DEBUG_REVOLUTION: return true;
#endif
#ifdef CONFIG_IR_SPOKE_DEBUG_SERIAL_BLE
        case IR_SPOKE_DEBUG_BLE: return true;
#endif
#ifdef CONFIG_IR_SPOKE_DEBUG_SERIAL_BLE_NOTIFY
        case IR_SPOKE_DEBUG_BLE_NOTIFY: return true;
#endif
#ifdef CONFIG_IR_SPOKE_DEBUG_SERIAL_CAN
        case IR_SPOKE_DEBUG_CAN: return true;
#endif
#ifdef CONFIG_IR_SPOKE_DEBUG_SERIAL_CAN_TX
        case IR_SPOKE_DEBUG_CAN_TX: return true;
#endif
#ifdef CONFIG_IR_SPOKE_DEBUG_SERIAL_ERRORS
        case IR_SPOKE_DEBUG_ERROR: return true;
#endif
        default: return false;
    }
#else
    (void)event;
    return false;
#endif
}

static bool led_enabled(ir_spoke_debug_event_t event) {
#if defined(CONFIG_IR_SPOKE_DEBUG_ENABLE) && defined(CONFIG_IR_SPOKE_DEBUG_LED)
    switch (event) {
#ifdef CONFIG_IR_SPOKE_DEBUG_LED_STARTUP
        case IR_SPOKE_DEBUG_STARTUP: return true;
#endif
#ifdef CONFIG_IR_SPOKE_DEBUG_LED_RMT
        case IR_SPOKE_DEBUG_RMT: return true;
#endif
#ifdef CONFIG_IR_SPOKE_DEBUG_LED_PULSE_ACCEPTED
        case IR_SPOKE_DEBUG_PULSE_ACCEPTED: return true;
#endif
#ifdef CONFIG_IR_SPOKE_DEBUG_LED_PULSE_REJECTED
        case IR_SPOKE_DEBUG_PULSE_REJECTED: return true;
#endif
#ifdef CONFIG_IR_SPOKE_DEBUG_LED_ESTIMATOR
        case IR_SPOKE_DEBUG_ESTIMATOR: return true;
#endif
#ifdef CONFIG_IR_SPOKE_DEBUG_LED_REVOLUTION
        case IR_SPOKE_DEBUG_REVOLUTION: return true;
#endif
#ifdef CONFIG_IR_SPOKE_DEBUG_LED_BLE
        case IR_SPOKE_DEBUG_BLE: return true;
#endif
#ifdef CONFIG_IR_SPOKE_DEBUG_LED_CAN
        case IR_SPOKE_DEBUG_CAN: return true;
#endif
#ifdef CONFIG_IR_SPOKE_DEBUG_LED_ERRORS
        case IR_SPOKE_DEBUG_ERROR: return true;
#endif
        default: return false;
    }
#else
    (void)event;
    return false;
#endif
}

static uint32_t led_pulse_ms(ir_spoke_debug_event_t event) {
    switch (event) {
        case IR_SPOKE_DEBUG_PULSE_ACCEPTED: return 15;
        case IR_SPOKE_DEBUG_PULSE_REJECTED: return 40;
        case IR_SPOKE_DEBUG_CAN_TX: return 20;
        case IR_SPOKE_DEBUG_REVOLUTION: return 100;
        case IR_SPOKE_DEBUG_STARTUP: return 100;
        case IR_SPOKE_DEBUG_RMT: return 150;
        case IR_SPOKE_DEBUG_ESTIMATOR: return 300;
        case IR_SPOKE_DEBUG_BLE: return 200;
        case IR_SPOKE_DEBUG_CAN: return 100;
        case IR_SPOKE_DEBUG_ERROR: return 700;
        default: return 50;
    }
}

static void signal_led(ir_spoke_debug_event_t event) {
#if defined(CONFIG_IR_SPOKE_DEBUG_ENABLE) && defined(CONFIG_IR_SPOKE_DEBUG_LED)
    if (!initialized || !led_off_timer || !led_enabled(event)) return;
    led_event_active = true;
    set_led(true);
    (void)esp_timer_stop(led_off_timer);
    (void)esp_timer_start_once(led_off_timer,
        (uint64_t)led_pulse_ms(event) * 1000ULL);
#else
    (void)event;
#endif
}
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

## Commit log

2026-07-27 Build integrated IR spoke link simulation and KiCad project
    [bom_jlcpcb.csv, ir_spoke_link.kicad_pcb, ir_spoke_link.kicad_sch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]
2026-07-27 Build discrete IR spoke sensor system and technical docs
    [bom_jlcpcb.csv, cable_bom.csv, ir_spoke_link.kicad_pcb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]
2026-07-27 Make IR carrier configurable and link full simulation stack
    [bom_jlcpcb.csv, ir_spoke_link.kicad_pcb, ir_spoke_link.kicad_sch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]
2026-07-31 Publish R4 IR wheel speed sensor project
    [IR_Spoke_Sensor_R4_2L-B_Courtyard.gbr, IR_Spoke_Sensor_R4_2L-B_Cu.gbl, IR_Spoke_Sensor_R4_2L-B_Mask.gbs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]
2026-07-31 Refresh PCB documentation render
2026-07-31 Release ordered hardware V0.1
    [IR_Spoke_Sensor_V0.1_2L-B_Courtyard.gbr, IR_Spoke_Sensor_V0.1_2L-B_Cu.gbl, IR_Spoke_Sensor_V0.1_2L-B_Mask.gbs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]
2026-07-31 Add Bluetooth CSC wheel sensor service
2026-08-19 Fix ESP32-S3 RMT RX glitch filter limit
2026-08-19 Correct ESP32-S3 firmware configuration defaults
2026-08-19 Add granular serial and LED debug instrumentation
2026-08-19 Make optical link visible on LED and serial
2026-08-19 Measure optical carrier with ESP32-S3 PCNT
2026-08-19 Fix PCNT virtual level configuration
    [ir_spoke_link_monitor.c]
